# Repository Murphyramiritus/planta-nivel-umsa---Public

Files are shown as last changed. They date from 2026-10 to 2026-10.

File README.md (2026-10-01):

# Planta de Nivel - UMSA

Repositorio de la escuadra de la planta de nivel de liquido.
Asignaturas concurrentes: ETN-902, ETN-1034, ETN-1000.

## Estructura

- `documentacion/planos_isa/` - planos P&ID y electricos (.dwg y .pdf)
- `documentacion/manuales_inversa/` - fichas tecnicas del Laboratorio 1
- `database/scripts/` - modelo E-R y scripts SQL (ETN-1000)
- `middleware/` - programas de comunicacion (Modbus, dashboard)
- `historico/` - material de semestres anteriores

Los videos e instaladores no se versionan: estan en Google Drive.
Ver `historico/README.md`.

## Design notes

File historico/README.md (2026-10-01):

# Historico de semestres anteriores

Material de escuadras anteriores. Credito a sus autores.
Los videos y programas estan en Google Drive.

| Semestre | Documentacion | Videos y archivos pesados |
|---|---|---|
| 1-BITACORA | [carpeta](1-BITACORA/) | PEGAR_ENLACE_DE_DRIVE |
| 2-BITACORA | [carpeta](2-BITACORA/) | PEGAR_ENLACE_DE_DRIVE |
| 3-BITACORA | [carpeta](3-BITACORA/) | PEGAR_ENLACE_DE_DRIVE |
| del-Descripción | [carpeta](del-Descripción/) | PEGAR_ENLACE_DE_DRIVE |
| DIAGNOSTICO_SNL | [carpeta](DIAGNOSTICO_SNL/) | PEGAR_ENLACE_DE_DRIVE |
| MANUAL_INSTRUCCIONES | [carpeta](MANUAL_INSTRUCCIONES/) | PEGAR_ENLACE_DE_DRIVE |
| VIDEOS_SNL | [carpeta](VIDEOS_SNL/) | PEGAR_ENLACE_DE_DRIVE |

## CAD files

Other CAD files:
historico/2022-II/DIAGRAMAS/NIVEL.dwg
historico/2022-II/DIAGRAMAS/NIVEL_DESCRIPCION.dwg

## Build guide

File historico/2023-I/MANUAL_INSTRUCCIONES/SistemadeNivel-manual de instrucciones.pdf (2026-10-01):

# Planta nivel de liquido MANUAL DE INSTRUCCIONES

CUIDADO

1. Lea estas instrucciones
2. Conserve el manual de instrucciones
3. Tenga en cuenta las advertencias
4. Siga las instrucciones
5. No utilice este sistema en lugares que tengan una pendiente muy pronunciada
6. Límpielo regularmente para no afectar la calidad del liquido
7. no obstruya los tanques con cualquier otro material
8. coloque el cable de alimentación en modo que no ejerza presión sobre él.
9. No lo instale en una ubicación donde sea difícil trabajar con el sistema
10. Prestar atención a los protectores de corriente de cada uno de los componentes

Atención

La planta no puede trabajar mas de 12 horas debido a que puede dejar de funcionar en óptimas condiciones

Se puede producir una sobre corriente en el uso del motor, esto será visible en el protector, ya que no permitirá que se sobre limite.

Se puede percatar que las partículas de polvo estarán presenten, por ello se indica nuevamente la limpieza de los tanques.

CUIDADO

En donde se utiliza un enchufe o adaptador como dispositivo para desconectar el enchufe, este debe permanecer en buenas condiciones de funcionamiento

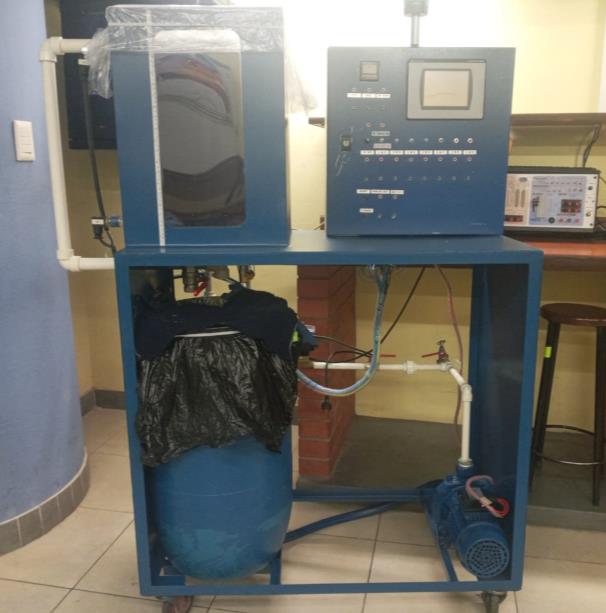
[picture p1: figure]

INDICE

### 1. COMO CONECTAR Y PREPARAR EL SISTEMA 2. FUNCIONAMIENTO BÁSICO 3. FUNCIONES DEL PLC 4. SENSOR ULTASONICO 5. ESPECIFICACIONES TÉCNICAS 6. GUÍA DE SOLUCIÓN DE PROBLEMAS DE FUNCIONAMIENTO

### 1. COMO CONECTAR Y PREPARAR EL SISTEMA 1.1 Componentes 1 Baliza de dos estados 2 Panel de control 3 Tanque de liquido 4 Tanque de líquido de retención

### 5 Bomba centrifuga 6 Sensores vibratorios 7 Sensor de presión 8 Sensor de temperatura

### 1.2 Energizar el sistema

- Conecta el cable AC al toma corriente
- seleccionar el selector eléctrico rotativo en ON

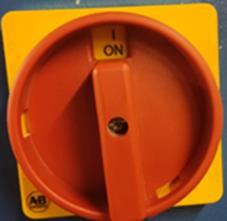
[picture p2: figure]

- Verifica el encendido de la lámpara de señalización “StandBy”

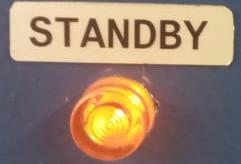
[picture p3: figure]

- Verifica el encendido de la lámpara de señalización “Ready”

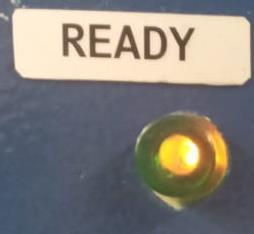
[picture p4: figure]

- Verificar el funcionamiento del dosificador y control de temperatura

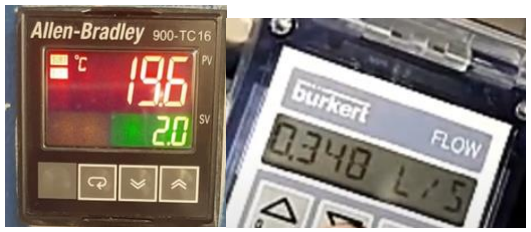
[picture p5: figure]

Visualizador de temperatura y dosificador

### 1.3 Activar todos los interruptores electromagnéticos

- Verificar el encendido del variador de frecuencia
- Verificar el encendido de las balizas.
- verificar el encendido del sensor ultrasónico y vibratorios

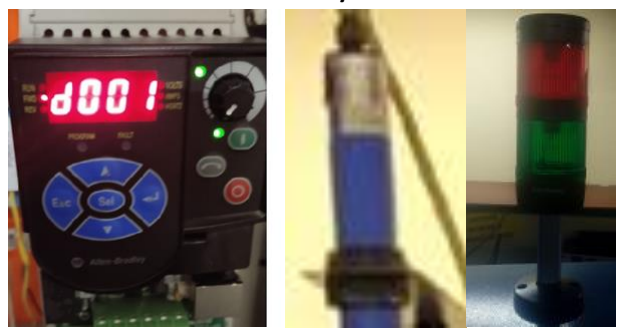
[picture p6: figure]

Variador de frecuencia, sensor ultrasónico y baliza

Activar la señal de control I0:3
- El PLC contiene el ultimo programa desarrollado en la materia

### 1.4 panel control

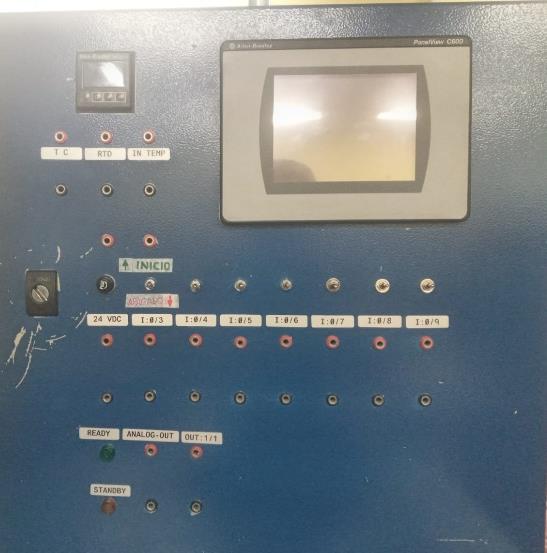
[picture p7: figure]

Para visualizar la temperatura en un sensor RTD y en sensor TC se realizarán las siguientes conexiones:

- Visualizador de temperatura
- Puertos de conexión del
visualizador de temperatura
- Interruptor de START y STOP de la planta
- puertos de conexión para los interruptores
- señalización de alimentación al sistema
- HMI

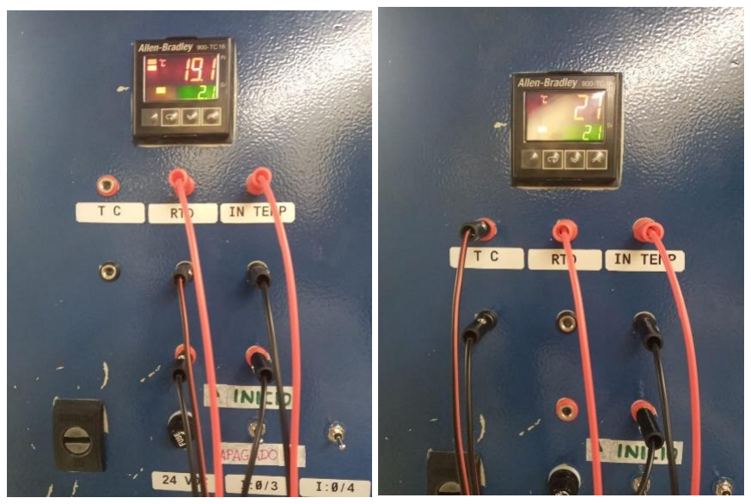
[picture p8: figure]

### 1.5 función de interruptores

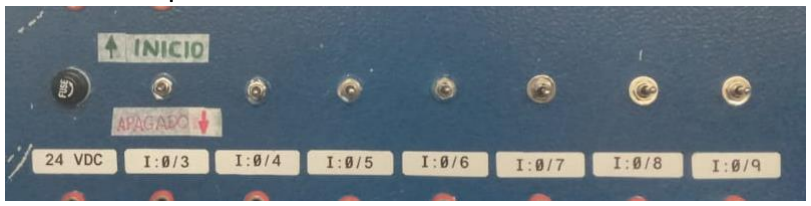
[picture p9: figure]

Se visualizan 9 interruptores de 3 estados, de los cuales, el primordial sera I:0/3 para la START Y STOP (solo usaremos 2 estados)
START (I:0/3 ==1):
- Activa la baliza a color verde
- Activa las electroválvulas NC
- Activa la alimentación de las salidas del PLC STOP (I:0/3 ==0):
- Activa la baliza a color rojo
- desactiva las electroválvulas NC
- desactiva la alimentación de las salidas del PLC

### 2. FUNCIONAMIENTO BÁSICO 2.1 Preparación de los tanques

Revisar que los tanques no presenten obstrucciones (de algún material extraño o de las válvulas manuales que se encuentran al inferior del tanque principal)

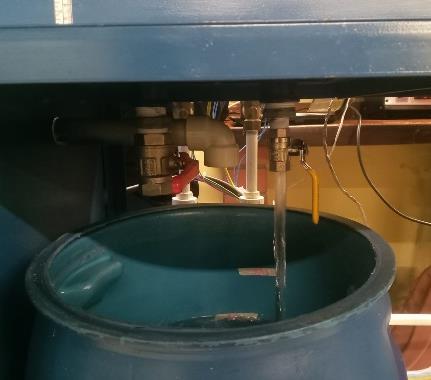
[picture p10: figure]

Válvulas manuales del tanque superior

### 2.2 encender y apagar

con el botón de encendido, realizara lo siguiente:
- el PLC obtendrá señales analógicas y mandará señal de control hacia el variador de frecuencia (conexión eléctrica).
- La altura de referencia (25 centímetros) será estable en un tiempo determinado (25 minutos).

### 2 FUNCIONES DEL PLC

El PLC tiene la función de controlar el sistema de nivel de líquido mediante la obtención de datos del nivel de líquido y la altura referencia.

### 2.1 Interfaz

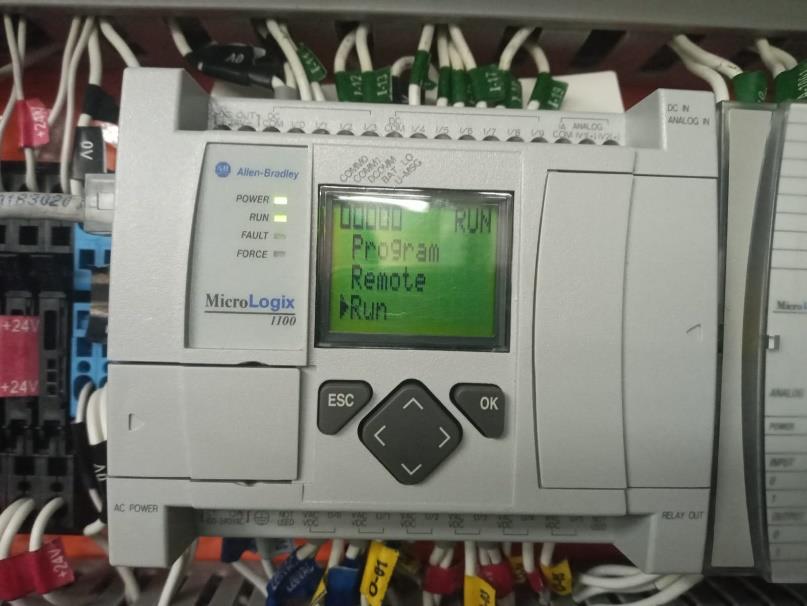
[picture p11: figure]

La interfaz principal presenta varias opciones de las cuales las que utilizaremos son: PROGRAM
RUN

### 2.2 Modo PROGRAM

Para realizar el cambio de la programación, mientras ello sucede el sistema no funciona, esto puede ser realizado con varias aplicaciones como RSx_logic.

### 2.3 Modo RUN

al aceptar el modo Run obtenemos el sistema funcionando listo para recibir las señales de encendido y apagado programadas.

### 3 SENSOR ULTRASONICO

El sensor nos ayudara a medir la altura del líquido en el tanque y recopilar la información en el PLC.

### 3.1 modo de uso

la medición de altura será proporcional a la corriente de salida de los pines del sensor (4-20mA).

### 4 ESPECIFICACIONES TÉCNICAS

Tamaño del sistema | 1.5m x 0,5m
Potencia activa del sistema | 2 kW
Capacidad del tanque inferior | 80 litros
Capacidad del tanque superior | 76 litros (aproximado)

### 5 GUÍA DE SOLUCIÓN DE PROBLEMAS DE FUNCIONAMIENTO

El sistema no enciende | - Verificar el encendido del variador de frecuencia - Verificar el encendido de las balizas. - verificar el encendido del sensor ultrasónico y vibratorios
El proceso no funciona | Verifique el variador de frecuencia este configurado correctamente. Verifique que en el PLC contenga su programa. Revise en el panel de control, la continuidad en cableado de todos los dispositivos Revise el estado de los fusibles.
No es posible poner la marcha al sistema con el interruptor I0:3 | Revisar si el PLC se encuentra en modo PROGRAMA, si es así, activar el modo RUN
El proceso funciona, pero no existe caudal de entrada | Verifique que el tanque inferior contenga líquido. Verifique el funcionamiento del actuador (Variador de frecuencia y bomba centrifuga). Verifique la correcta posición de las válvulas manuales. Verifique el funcionamiento de las electroválvulas eléctricas.
El proceso funciona de forma incorrecta | Revise el funcionamiento de los sensores (el último programa implementado en el PLC solo utiliza el sensor ultrasónico). Vuelva a calibrar el sensor de nivel(ultrasónico), para la correcta lectura de datos.

Electroválvulas no funciona correctamente Se necesita desmontar la electroválvula y verificar su funcionamiento eléctrico (energización del solenoide) . Realizar una limpieza exhaustiva a los elementos mecánicos internos, debido a la acumulación de suciedad o elementos extraños.

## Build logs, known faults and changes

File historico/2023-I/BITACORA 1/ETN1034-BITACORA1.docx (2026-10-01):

Universidad “Mayor de San Andrés”

FACULTAD DE INGENIERIA

LABORATORIO 1

CONTROLADOR DEL SISTEMA DE NIVEL DE LIQUIDO

Integrantes: Univ. Arias Llampaso Leidy Melany

Univ. Espino Marca Mary Isabel

Univ.Laura Mamani Vania Cindy

Univ. Ramos Apaza Marco Daniel

Carrera: Ing. Electrónica

Materia: Aplicación de Técnicas de Control ETN 1034

Docente: Jorge A. Nava A.

Fecha: 1/05/2023

La Paz – Bolivia

# 1. OBJETIVOS

- Reconocimiento y ubicación de los componentes del sistema (actuadores, sensores, controladores, transductores, etc.)
- Principio de funcionamientos de los componentes del sistema.
- Medir y monitorear continuamente el nivel de líquido en el tanque.
- Mantener el nivel dentro de un rango específico y controlado para garantizar un funcionamiento eficiente.
- Integrar un controlador para garantizar un monitoreo y control continuo.

# 2. DESCRIPCION DEL PROCESO

El sistema de nivel de líquido tiene como propósito medir la cantidad de líquido en un recipiente o tanque. Esto es importante en muchas aplicaciones industriales y de ingeniería, donde la cantidad precisa de líquido en un proceso es crítica para su eficiencia y seguridad.

El sistema de nivel de líquido puede ser utilizado para controlar el llenado y vaciado de un tanque, o para alertar a los operadores cuando el nivel de líquido está demasiado alto o demasiado bajo y para mantener un volumen deseado de líquido contenido en el tanque.

Del proceso también podemos obtener información sobre la presión y la temperatura.

# 3. ELEMENTOS DEL SISTEMA

## 3.1. Estructura del sistema:

- Estructura metálica color azul
- Dos tanques de almacenamiento de agua
- Soporte para sensores
- Tablero de control
- Tuberías de ½ y ¾

Tablero de control

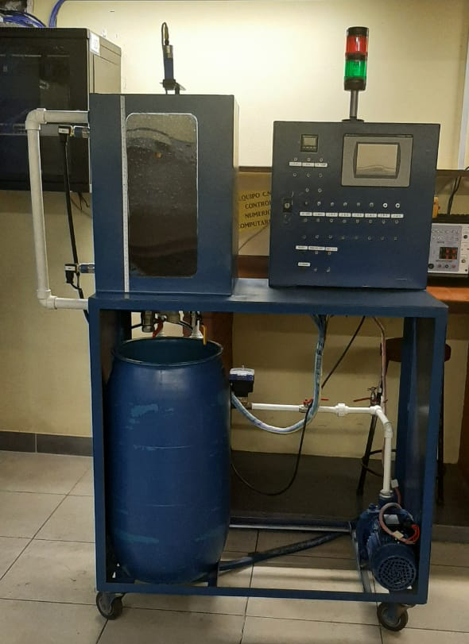
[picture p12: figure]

Tanque fijo de metal

Tanque de plástico

Tubería de ½ pulgada

## 3.2. Componentes del sistema:

- 2 sensores vibratorios
- 2 electroválvulas
- Flujómetro digital (Dosificador)
- Sensor de presión
- Sensor de temperatura TC (Termocupla)
- Sensor de temperatura RTD (Resistivo)
- Controlador de temperatura
- motor trifásico de 1HP
- Variador de frecuencia
- Sensor de Ultrasonido
- PLC (Micrologix 1100)
- 1 módulo de expansión (para PLC)
- Fuente de alimentación de 24V
- Pantalla de 6 pulgadas touch Panelview C600

Sensor ultrasónico

Sensor Vibratorio

Motor trifásico de 1 HP

Sensor ultrasónico

Controlador de temperatura

HMI

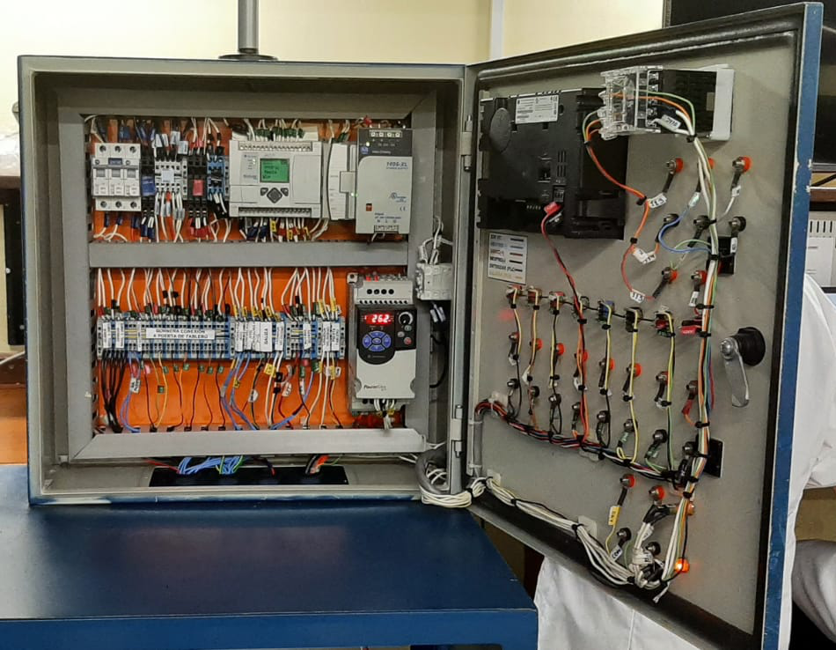
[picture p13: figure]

PLC

Módulo de expansión

Fuente de alimentación de 24 V

Variador de frecuencia

Fig. Vista frontal del sistema

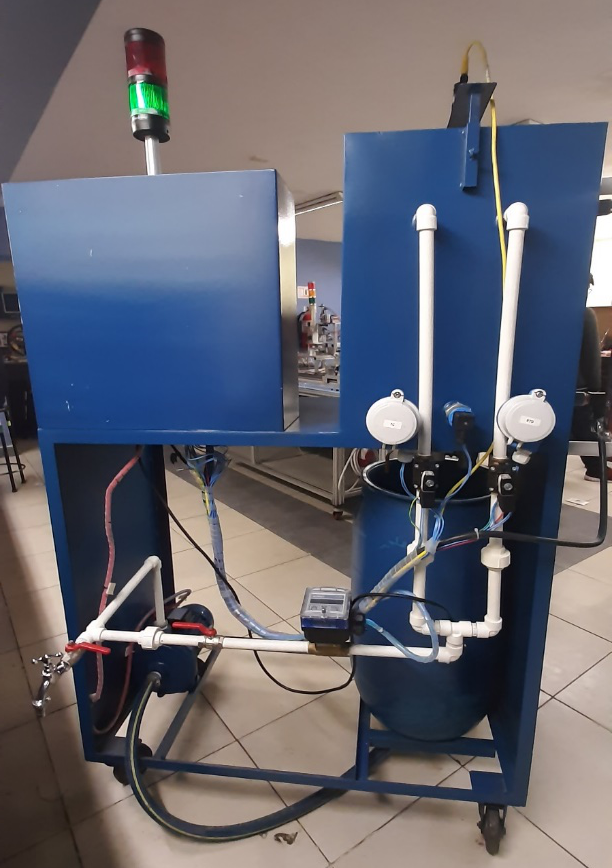
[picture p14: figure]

Sensor de Presión

Sensor de temperatura RTD

Sensor de Temperatura TC

Dosificador

Fig. Vista posterior del sistema

# 3. PROTECCION

## 3.1. Dispositivo de protección

Un termomagnético es utilizado en los sistemas eléctricos para evitar sobrecargas y cortocircuitos. Consiste en un dispositivo combinado que incluye tanto un interruptor térmico como un interruptor magnético. La función del interruptor térmico es proteger contra sobrecargas eléctricas prolongadas, es decir, corrientes excesivas que puedan dañar los cables o los dispositivos conectados. Cuando la corriente supera un cierto umbral durante un período de tiempo determinado, el interruptor térmico se activa y desconecta el circuito eléctrico, interrumpiendo el flujo de corriente.

Por otro lado, el interruptor magnético protege contra cortocircuitos, que son corrientes eléctricas muy altas que ocurren cuando hay un contacto directo entre conductores de diferentes polaridades. El interruptor magnético detecta rápidamente estas corrientes y desconecta el circuito eléctrico de manera inmediata para prevenir daños mayores.

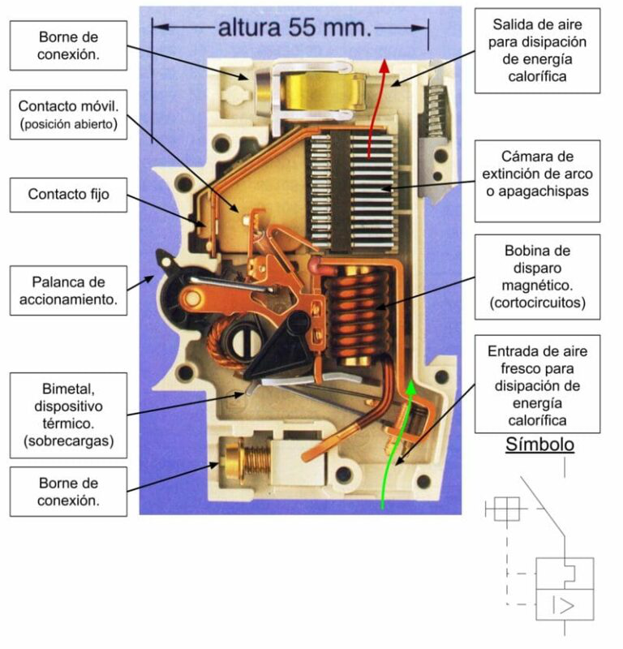
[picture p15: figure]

Los fusibles son dispositivos pequeños de seguridad que forman parte de las instalaciones eléctricas, los cuales se funden cuando la corriente alcanza ciertos valores excesivos. Se conforman por una lámina o un filamento hecho de una aleación o de un metal que se destaca por presentar un punto de fusión bajo.

Fig. Fusibles

Fig. Partes de un magnetotérmico

## 3.2. Medidas AWG

Imagen | Calibre AWG | Diámetro en MM | Consumo | Usos
| 6 | 16mm | Muy Alto | Aires acondicionados centrales, equipos industriales (se requiere instalación especial de 240 volts).
| 8 | 10mm | Alto | Aires acondicionados, estufas eléctricas y acometidas de energía eléctrica.
| 10 | 6mm | Medio-Alto | Secadoras de ropa, refrigeradores, aires acondicionados de ventana.
| 12 | 4mm | Medio | Hornos de microondas, licuadoras, contactos de casas y oficinas, extensiones de uso rudo.
| 14 | 2.5mm | Medio-Bajo | Cableado de iluminación, contactos de casas, extensiones reforzadas.
| 16 | 1.5mm | Bajo | Extensiones de bajo consumo, lámparas.
| 18 | 1mm | Muy Bajo | Productos electrónicos como termostatos, timbres o sistemas de seguridad.

En la planta se cuenta con los siguientes calibres:

CALIBRE DEL CABLEADO DEL SISTEMA DE NIVEL DE LÍQUIDO:

Fuente de alimentación | entradas y salidas | 12 AWG
HMI | Energización | AWG 18
Control de temperatura | Energización | 12 AWG
TC, RTD, presión, electroválvulas | | 16 AWG y 18 AWG
Interruptor de palanca Y CONECTORES | | AWG 18
Lámparas piloto
Sensor vibratorio | | AWG 16
Tablero | | 16 AWG
Sensor ultrasonico | | 18 AWG
PLC y módulo de expansión | | 16 AWG
Variador de Frecuencia y Bomba centrifuga | | 12 AWG

# 4. SEÑALIZACION

## 4.1. Baliza luminosa

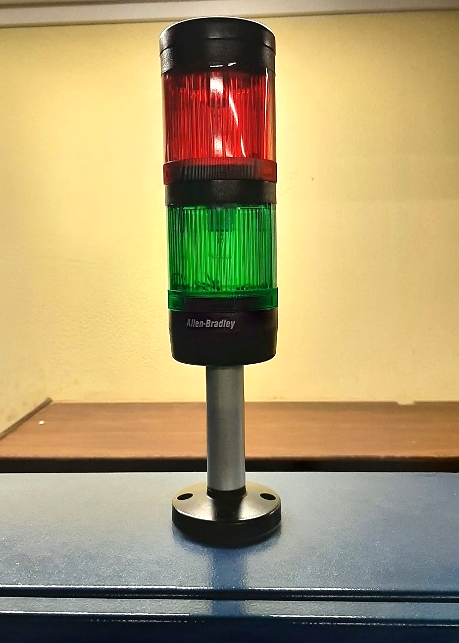
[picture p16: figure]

En un entorno industrial, una baliza es un dispositivo de señalización visual que se utiliza para indicar estados de seguridad, advertencias o información importante. Por lo general, las balizas industriales son luces de gran intensidad y colores llamativos, como rojo, amarillo o verde, a menudo se colocan en lugares estratégicos para asegurar una buena visibilidad. Las balizas industriales se utilizan para indicar el estado de un proceso, la presencia de una condición peligrosa o para llamar la atención del personal en situaciones específicas.

En nuestro sistema o kit tiene una baliza de dos colores, rojo y verde, el cual dependiendo en que etapa este, señaliza el funcionamiento del sistema, la programación depende del operador del equipo.

El sistema de señalización es simple de entender y de conectar, en este caso se usa solo los colores, los cuales están alimentados con +24 VCC

Fig. Baliza luminosa

## 4.2. Luces piloto

Las luces piloto en un sistema industrial suelen ser pequeñas luces que se utilizan para indicar el estado de funcionamiento de un equipo o sistema. Estas luces son de tamaño reducido y generalmente se encuentran en paneles de control, tableros de instrumentos o equipos individuales. Las luces piloto pueden tener diferentes colores. Las luces piloto proporcionan una indicación rápida y visual del estado de un sistema y son utilizadas por los operadores para monitorear y controlar los equipos.

Las luces piloto están disponibles para brindar control visual de que se está llevando a cabo una función eléctrica en una ubicación local o remota

Fig. Luces Piloto

# 5. ESQUEMAS

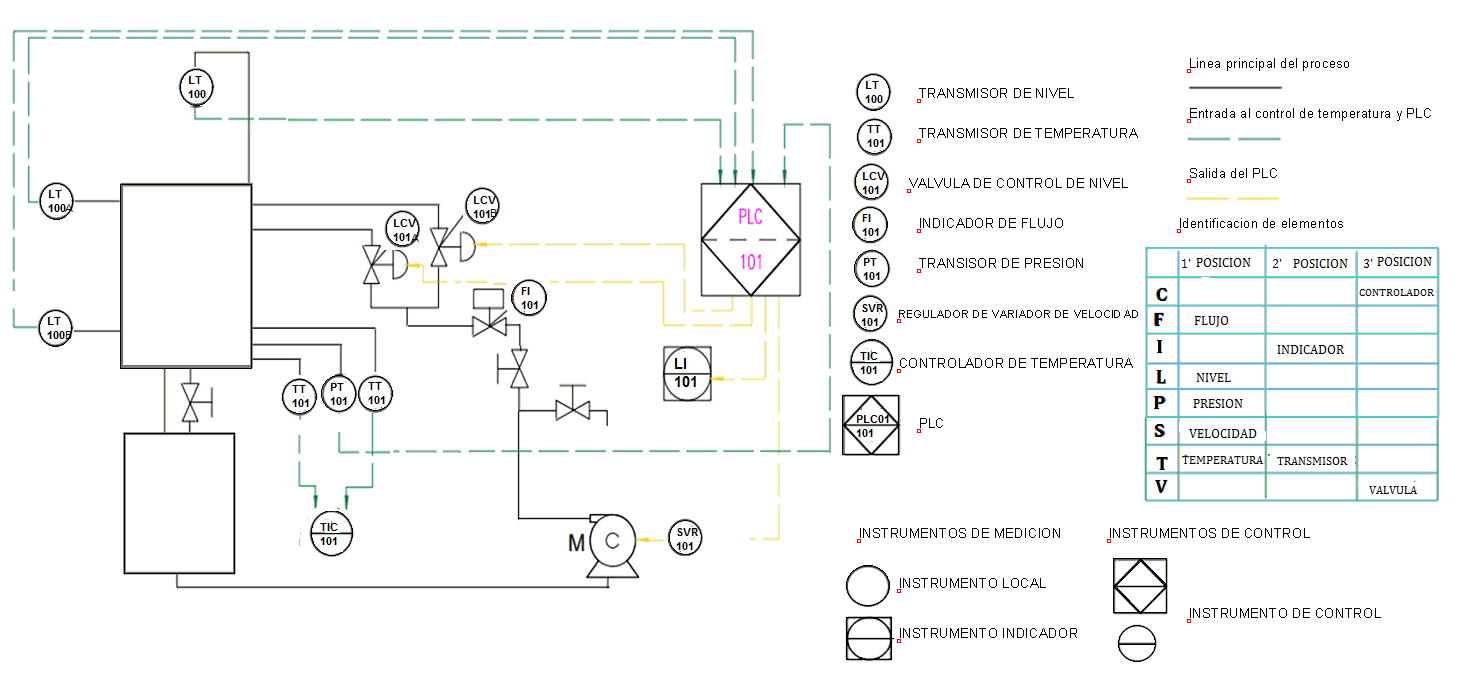
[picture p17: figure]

## 5.1. Diagrama P&ID

## 5.2. Esquema Eléctrico

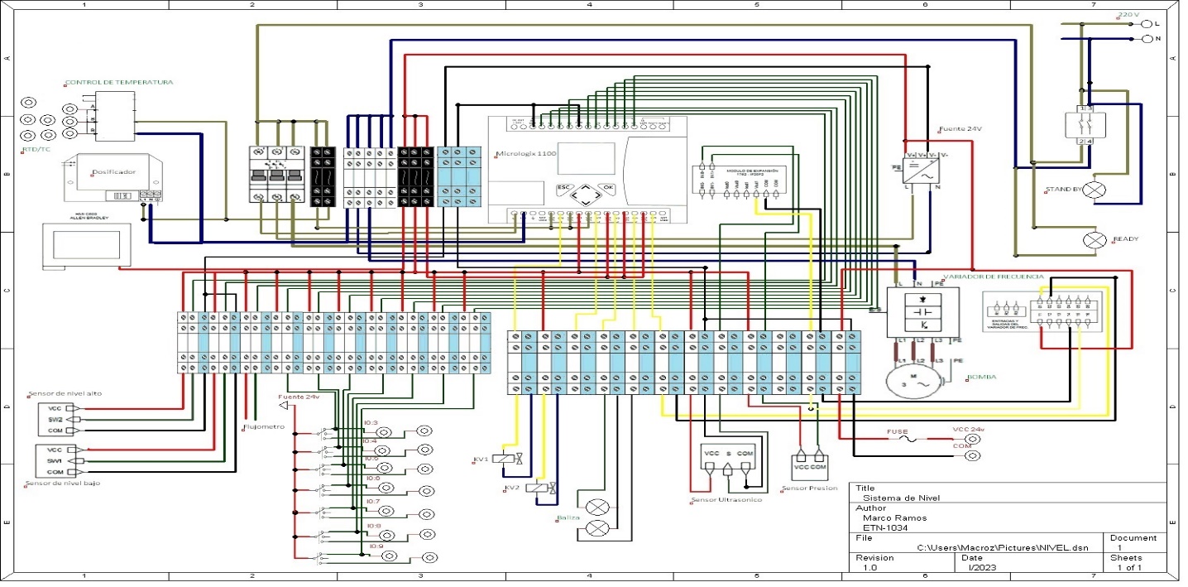
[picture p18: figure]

# 6. PUESTA EN MARCHA DEL SISTEMA

COMO CONECTAR Y PREPARAR EL SISTEMA

  - Energizar el sistema
- Conecta el cable AC al toma corriente
- seleccionar el selector eléctrico rotativo en ON
- Verifica el encendido de la lámpara de señalización “StandBy”

- Verifica el encendido de la lámpara de señalización “Ready”

- Verificar el funcionamiento del dosificador y control de temperatura

Visualizador de temperatura y dosificador

  - 1.3 Activar todos los interruptores electromagnéticos

- Verificar el encendido del variador de frecuencia

- Verificar el encendido de las balizas.

- verificar el encendido del sensor ultrasónico y vibratorios

Variador de frecuencia, sensor ultrasónico y baliza

Activar la señal de control I0:3

- El PLC contiene el último programa desarrollado en la materia
  - Panel control
- Visualizador de temperatura
- Puertos de conexión del visualizador de temperatura
- Interruptor de START y STOP de la planta
- puertos de conexión para los interruptores
- señalización de alimentación al sistema
- HMI

Para visualizar la temperatura en un sensor RTD y en sensor TC se realizarán las siguientes conexiones:

  - Función de interruptores

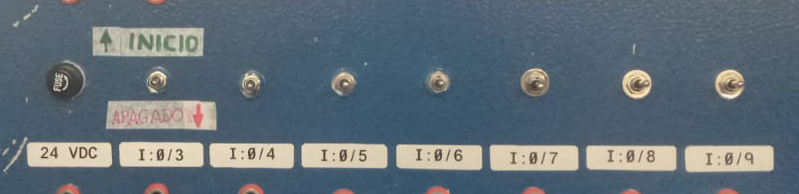
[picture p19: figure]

Se visualizan 9 interruptores de 3 estados, de los cuales, el primordial sera I:0/3 para la START Y STOP (solo usaremos 2 estados)

START (I:0/3 ==1):

- Activa la baliza a color verde
- Activa las electroválvulas NC
- Activa la alimentación de las salidas del PLC

STOP (I:0/3 ==0):

- Activa la baliza a color rojo
- desactiva las electroválvulas NC
- desactiva la alimentación de las salidas del PLC

FUNCIONAMIENTO BÁSICO

  - Preparación de los tanques

Revisar que los tanques no presenten obstrucciones (de algún material extraño o de las válvulas manuales que se encuentran al inferior del tanque principal)

Fig. Válvulas manuales del tanque superior

  - Encender y apagar

con el botón de encendido, realizara lo siguiente:

- el PLC obtendrá señales analógicas y mandará señal de control hacia el variador de frecuencia (conexión eléctrica).
- La altura de referencia (25 centímetros) será estable en un tiempo determinado (25 minutos).

FUNCIONES DEL PLC

El PLC tiene la función de controlar el sistema de nivel de líquido mediante la obtención de datos del nivel de líquido y la altura referencia.

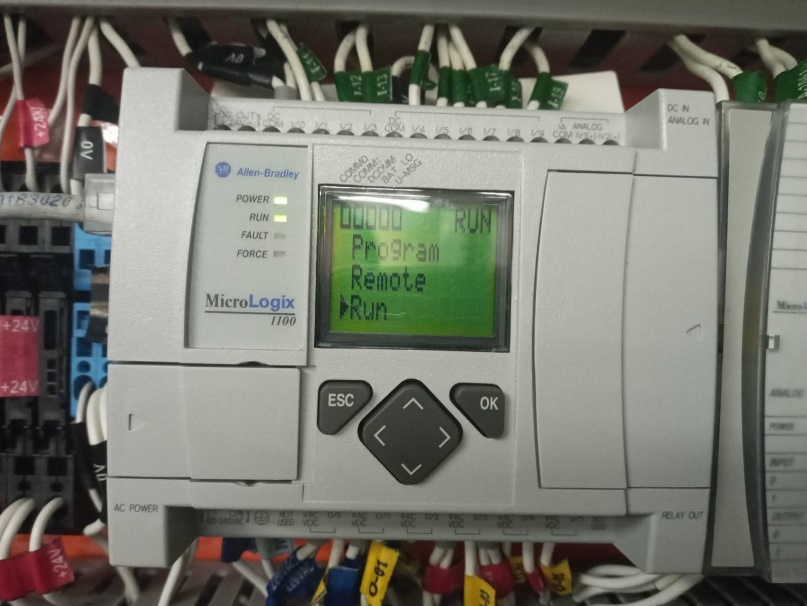
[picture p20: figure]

Interfaz

La interfaz principal presenta varias opciones de las cuales las que utilizaremos son:

PROGRAM

RUN

Modo PROGRAM

Para realizar el cambio de la programación, mientras ello sucede el sistema no funciona, esto puede ser realizado con varias aplicaciones como RSx_logic.

Modo RUN

al aceptar el modo Run obtenemos el sistema funcionando listo para recibir las señales de encendido y apagado programadas.

# 7. INSTRUMENTACION

Los instrumentos que utilizaremos en laboratorio son:

- Multímetros
- Temporizadores
- Escalas de medición
- Sensor de temperatura
- Pistola de calor
- Cable ethernet
8. COMPONENTES DEL SISTEMA

## 8.1. ACTUADORES

### 8.1.1. Variador de frecuencia

Principio de funcionamiento: La velocidad síncrona de un motor de corriente alterna (CA) está determinada por la frecuencia de AC suministrada y el número de polos en el estator, de acuerdo con la relación:

RPM=(120×f)/p

Donde:

RPM = Revoluciones por minuto

f = frecuencia de suministro AC [Hz]

p = Número de polos

24 V

0 V

O05

COM

A1012

Características POWERFLEX 4M

Entradas y salidas del variador de frecuencia:

5 entradas digitales | 2 programables
1 entrada analógica | 0 a 10 VDC
1 entrada analógica | 4 a 20 mA.
1 salida digital tipo relé

Fig Entradas y salidas del variador de frecuencia

En el sistema solo se utilizan 2 entradas digitales para realizar el arranque del motor y con la entrada analógica de 4 a 20 mA se realiza un control a 2 hilos de esta manera se puede manejar el variador de manera remota

Configuración de parámetros del motor para el variador de frecuencia:

1. Medir las conexiones
  - Entre el pin 11(24 [V]) y el pin 4(digital común) el voltaje medido es: 24,7 [V], Existen dos modos SRC y SNK
2. Restablecer a predeterminado
- P112: colocar en 1 y luego aparecerá el error f048, el cual debe ser borrado con stop.
3. Configurar voltaje placa motor
  - P101: 230[V]
4. Configurar frecuencia nominal
  - P102: 50 [Hz]
5. Configurar Corriente máxima
  - P104: 3,4 [A]
6. Configurar Frecuencia máxima y minima
- P104: 0 [Hz] min
- P105: 50 [Hz] max
7. Configurar Arranque por teclado
  - P106: “0” (modo por teclado)
8. Inhabilitar reversa
  - P104: “1” (inhabilita)

CARACTERIZACION

VARIADOR DE FRECUENCIA | VOLTAJE
0 | 0
5 | 38,8
10 | 57,5
15 | 77,3
20 | 98,1
25 | 119,3
30 | 144,4
35 | 170
40 | 195,1
45 | 219,9
50 | 229,9

### 8.1.2. Bomba centrifuga

principio de funcionamiento: Una bomba centrífuga es un tipo de bomba hidráulica que utiliza la fuerza centrífuga generada por un impulsor rotativo para aumentar la presión y mover fluidos.

- La bomba centrífuga consta de varios componentes. El impulsor es un componente clave que consta de palas curvadas que giran dentro de la carcasa de la bomba.
- Cuando el impulsor gira, crea una fuerza centrífuga que empuja el fluido hacia el exterior y hacia una zona de alta presión llamada difusor.
- El difusor es una estructura en forma de cono o voluta que rodea al impulsor y tiene la función de convertir la energía cinética del fluido en energía de presión.
- A medida que el fluido pasa a través del difusor, la velocidad disminuye y la presión aumenta

Utiliza un motor asíncrono trifásico, también conocido como motor de inducción trifásico, es un tipo de motor eléctrico que utiliza tres corrientes eléctricas alternas que son desfasadas entre sí en 120 grados para crear un campo magnético rotativo que hace girar el motor.

Este tipo de motor se compone principalmente de dos partes: el estator y el rotor. El estator es la parte fija del motor y se compone de un núcleo de hierro laminado, que contiene tres devanados de cobre, conectados en estrella o en triángulo, a través de los cuales circulan las corrientes eléctricas alternas trifásicas.

El rotor, por otro lado, es la parte móvil del motor y se compone de un conjunto de conductores de cobre dispuestos en ranuras de un núcleo de hierro laminado, los cuales están aislados eléctricamente y que forman una jaula de ardilla.

Cuando se aplica corriente eléctrica al estator, se produce un campo magnético rotativo que induce corrientes eléctricas en la jaula de ardilla del rotor. Estas corrientes crean un campo magnético en el rotor que interactúa con el campo magnético del estator, haciendo que el rotor comience a girar.

Características Pentax CMT 100/00

Q (l/min) | 20 / 90
H (m) | 32.5 / 25
HP | 1
kW | 0.74
V∆ | 230V
Vℷ | 400V
CL | Máxima temperatura de operación °F = 155°C
A | 3.4 2
Hz | 50
RPM del motor | 2800
IP 44 | Protección (resistente al agua)
Continuous Duty | Funcionamiento de motor de forma continua
3 phase | Motor trifásico para CA
CMT | Motor Centrífugo - Trifásico
00 | Armazón de hierro/Impulsor de Noryl

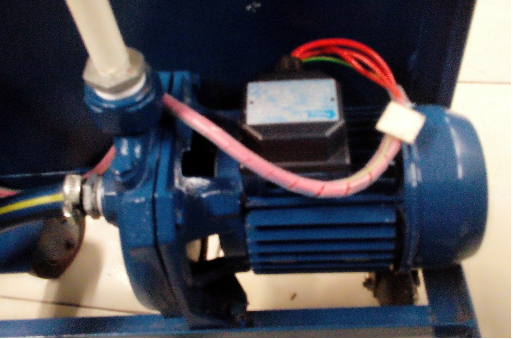
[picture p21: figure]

Fig. Bomba Centrifuga

CARACTERIZACION

FRECUENCIA [Hz] | CORRIENTE (SIN AGUA) [mA]
5 | 1,68
10 | 1,79
15 | 1,82
20 | 1,85
25 | 1,93
30 | 2,08
35 | 2,26
40 | 2,47
45 | 2,75
50 | 2,95

### 8.1.3. Electroválvulas

Principio de funcionamiento: El dispositivo cuya función es regular el flujo, en este caso hablamos del agua.

- La membrana de la válvula se apoya en el cuerpo con la ayuda del muelle y evita que el agua pase por la presión que ella misma ejerce
- Al momento de mandar una señal eléctrica al solenoide de la válvula, la bobina se imanta y levanta el embolo.
- De esta manera queda un pequeño agujero en la tapa de la válvula y permite salir al liquido de la cámara superior.
- Esto hace que funcione como un actuador que hace que se comuniquen la entrada y la salida de líquido del cuerpo de la válvula

bobina (A); armadura (B); anillo de sombra (C); muelle (D); émbolo (E); junta (F); cuerpo de la válvula (G)

CARACTERISTICAS

Fig. Electroválvula KV1

Tipo de electroválvula | 2/2 NC (2 posiciones, 2 vías, normalmente cerrado)
Suministro de voltaje 230 V AC | 230 V AC
Orificio | 13.0mm
Material de sellado | NBR
Presión nominal | 5 – 10 bar
Potencia de consumo | 4W
Temperatura de funcionamiento | 0 – 70°C

DIAGNOSTICO

- El día 13 de abril, se llevó a cabo la limpieza interna de una electroválvula que presentaba fallas en su funcionamiento.
- Se desmonto la válvula y se procedió a limpiar minuciosamente su interior, eliminando los residuos acumulados que obstruían el flujo de líquido.
- Una vez realizada la limpieza, se realizó una prueba de funcionamiento.
- Se pudo comprobar que la electroválvula funciona con normalidad y sin inconvenientes.

Fig. Electrovalvulas

## 8.2. Sensores

### 8.2.1. Sensor de vibración

principio de funcionamiento: Cuando se produce una vibración o movimiento oscilante, las horquillas oscilan en direcciones opuestas debido a su flexibilidad.

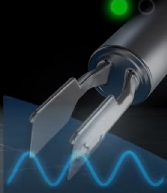
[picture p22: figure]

- Estas oscilaciones generan cambios en la resistencia eléctrica de las horquillas debido a un fenómeno conocido como efecto piezoeléctrico.
- El efecto piezoeléctrico implica que ciertos materiales generan una carga eléctrica cuando se deforman mecánicamente
- las horquillas del sensor vibratorio, están hechas de un material piezoeléctrico que genera una señal eléctrica proporcional a la amplitud y frecuencia de la vibración.
- Cuando las horquillas oscilan, la resistencia eléctrica del material cambia, lo que se traduce en una variación en la corriente eléctrica que fluye a través de ellas. Esta variación de corriente se detecta y se convierte en una señal eléctrica de salida.

Fig. Sensor vibratorio

CARACTERISTICAS

Suministro | 10-35 [V] DC
Temperatura del proceso | -40C – 150C
Presión de proceso absoluta | vacío 40 [Bar]
Densidad mínima del medio | 0.7 [g/cm^3]
Longitud del sensor | 64 [mm]
Frecuencia de medición | 1100Hz aprox. en aire
Tiempo de estabilización: | 2 [seg]

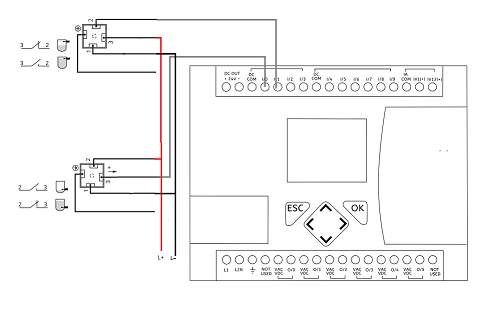
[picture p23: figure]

Fig. Sensor vibratorio inferior

### 8.2.2. Sensor de presión

principio de funcionamiento: El dispositivo detecta la presión utilizando una cavidad de presión y un diafragma de aislamiento para formar un capacitor variable

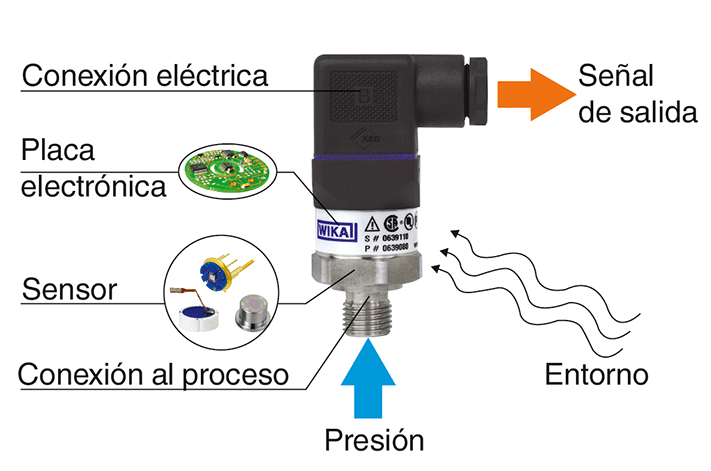
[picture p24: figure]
Cómo funciona un transmisor de presión? - Blog de WIKA

- La presión del proceso provoca una ligera desviación del diafragma de aislamiento del proceso del sensor cerámico.
- El cambio proporcional a la presión en la capacitancia se mide en los electrodos del sensor cerámico
- Este cambio en la capacidad se puede medir eléctricamente y correlacionarse con la presión aplicada
- El sensor capacitivo no requiere liquido de llenado, por tanto, también puede trabajar en aire.

CARACTERISTICAS CERABAR T-PMC131

Tipo de sensor de presión | Sensor capacitivo de cerámica
Suministro de voltaje | 11 – 30 [V] DC
Temperatura del proceso | -20C – 100C
Celda de medición | 100 mbar – 40 Bar
Limite máx.. de sobre presión | 60 bar
Comunicación | 4- 20mA (analógico)
Potencia máxima | 6W

Fig. Sensor de presión

DIAGNÓSTICO

No se encontró ninguna observación visual, externa e interna, debido a ello se procedió a realizar pruebas de funcionamiento y obtener una tabla de valores respecto con el llenado del líquido.

CARACTERIZACION

Altura [cm] | Corriente prueba [mA]
0 | 3,8
5 | 4,2
10 | 4,2
15 | 4,7
20 | 5,19
25 | 5,4
30 | 5,8
35 | 6,3
40 | 6,72

### 8.2.3. Sensor de temperatura TC

PRINCIPIO DE FUNCIONAMIENTO

Los termopares son sensores de temperatura robustos cuyo principio de medición se basa en el efecto Seebeck.

- Consta de dos hilos metálicos homogéneos pero diferentes entre sí y aislados en toda su longitud. Los dos cables son soldados juntos en un extremo
- El extremo es llamado “unión caliente o de medición” y el otro extremo es conocido como “unión fría o de referencia”
- Cuando se conectan en un punto los dos conductores eléctricos de distintos materiales, puede medirse una tensión eléctrica débil entre los dos extremos abiertos
- Siempre que haya un gradiente de temperatura en los conductores, esta tensión es denominada “tensión termo eléctrica”

CARACTERISTICAS TERMOCUPLA TD12

Tipo de sensor | TC12 “J” termómetro TC modular
Rango de temperatura de operacion: | -40°C – 750°C
Máxima presión de proceso | a 20°C es 40 bar (580psi)
Consumo de corriente | < 50mA
Rango de temperatura | - 20 °C– 70 ° C
Material | plástico - PBT

Fig. Sensor de temperatura TC

DIAGNOSTICO

El sensor no presentaba daños visualmente, por lo que se procede a realizar las pruebas de funcionamiento.

Por lo que procedemos a conectar el los pines del sensor un termómetro digital para obtener los datos de salida.

Multímetro °C | T[°C] | V[mV]
24 | 26 | 0
30 | 30 | 0,1
40 | 46 | 0,1
50 | 64 | 0,3
60 | 78 | 0,6
70 | 97 | 0,8
80 | 109 | 1
90 | 124 | 1,3
100 | 137 | 1,4
110 | 150 | 1,7
120 | 172 | 2,2
130 | 182 | 2,3

### 8.2.4. Sensor de temperatura RTD

principio de funcionamiento: El dispositivo realiza medidas de temperatura utilizando como factor principal de medición la resistencia de un metal.

- La resistencia del alambre de metal se transforma con relación a la temperatura, el funcionamiento de la RTD comienza al calentarse un metal
- Esta acción permite un aumento de temperatura induciendo una mayor agitación térmica y aumento de la resistencia.
- Se maneja el concepto de a mayor temperatura, mayor agitación y mayor Resistencia y a menor temperatura, se tiene menor agitación y menor Resistencia.
- La relación resistencia-temperatura se representa con la siguiente formula: R=Ro[1+a(T-To)]

CARACTERISTICAS RTD OMNIGRAND T TST487

Tipo | A, Métrico, porta sondas de temperatura modular conexión a proceso roscada sin cuello
Elemento sensible | Resistencia de platino
Conexión a proceso | Rosca macho G1/2
Rango de temperatura | -50°C – 300°C
Max. Presión de proceso | a 20°C 20bar
Alambrado | Conexión de 4 hilos, aislamiento de fibra de vidrio.

CARACTERIZACION

Fig. Sensor de temperatura RTD

MULT. °C | T[°C] | V [mV] | I[mA] | R[Ω]
40 | 44 | 118 | 1 | 118
60 | 71,4 | 127,8 | 1 | 127,8
70 | 87,5 | 134,6 | 1 | 134,6
80 | 92,9 | 136,4 | 1 | 136,4
90 | 98,7 | 138,6 | 1 | 138,6
100 | 104,1 | 141 | 1 | 141
110 | 110,8 | 142,8 | 1 | 142,8
120 | 131,8 | 150,9 | 1 | 150,9
140 | 134,5 | 151,6 | 1 | 151,6
150 | 150,1 | 157,7 | 1 | 157,7
160 | 154,9 | 158,9 | 1 | 158,9
170 | 159,3 | 160,2 | 1 | 160,2
180 | 167,7 | 163,7 | 1 | 163,7
190 | 170,5 | 164 | 1 | 164
200 | 179,1 | 168,7 | 1 | 168,7

### 8.2.5. Sensor ultrasónico

PRINCIPIO DE FUNCIONAMIENTO

Se basa en el principio de medida “Time of flight” y van detectando continuamente el nivel del líquido en el tanque

- Pulsos ultrasónicos son emitidos reflejados en la superficie del líquido y son recibidos por el sensor
- La distancia entre el instrumento y el líquido se puede calcular midiendo el “tiempo de vuelo”.
- Las ondas ultrasónicas, son ondas mecánicas, generados piezo- eléctricamente y reflejados en la superficie del líquido debido a la diferencia de densidad entre el aire y el liquido
- El periodo de tiempo medido y analizado por el instrumento, entre enviar y recibir el pulso, es una medida directa para calcular la distancia entre la membrana del sensor y la superficie del liquido

CARACTERISTICAS

Suministro de voltaje | 12 – 30 V DC
Salida | corriente analógica 4-20mA
Salida | Voltaje analógico 0-10 V
Rango de medición | 150 – 1500mm
Consumo de corriente | < 45mA
Rango de temperatura | - 20 – 70°C
Protección contra corto circuitos y sobrecarga

DIAGNOSTICO

El sensor ultrasónico no presentaba ningún problema visualmente, por lo que se procedió a probar su funcionamiento.

- El sensor inicialmente ya presentaba una calibración, pero se procedió a realizarlo nuevamente.
- Se realizaron las medidas máximas de distancia, que será la menor altura (H=0) y la mínima distancia (Hmax)
- La calibración se la realiza mediante el botón de configuración y se procede a guardar el rango de distancia de trabajo con ayuda de la hoja técnica.
- Una vez calibrado, procedemos a realizar la prueba de funcionamiento obteniendo la table de datos a continuación.

CARACTERIZACION

Altura del tanque [cm] | Corriente [mA]
20 | 19,1
25 | 17,1
30 | 15,1
35 | 13
40 | 10,9
45 | 8,8
50 | 6,8
55 | 4,8

SENSOR ULTRASONICO CON P1=56,8cm y P2=15cm

Altura del tanque [cm] | Corriente [mA]
0 | 3,7
5 | 5,3
10 | 7,1
15 | 9
20 | 11
25 | 12,8
30 | 14,7
35 | 16,5
40 | 18,4
45 | 19,3

## 8.3. AUTÓMATAS

### 8.3.1. Controlador lógico programable PLC

Funcionamiento: Detecta diversos tipos de señales del proceso, elaborar y enviar acciones, recibe configuraciones de los operadores y da reporte a los mismos.

Partes principales son la CPU, un módulo de memorias y de entra das/salidas, la fuente de alimentación y la unidad de programación.

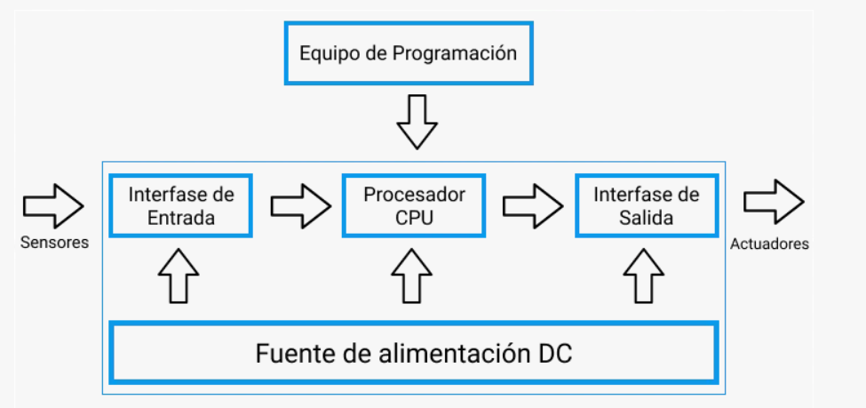
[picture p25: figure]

Fuente de alimentación DC
Módulos de entrada y salida
Unidad de procesamiento central (CPU)
Equipo de programaciónEstructura de un PLC

Módulos de entrada y salida (E / S)

- Son de dos tipos. Puede ser digital o analógico.
- Se debe proporcionar información al controlador PLC.
- M.E: Proporcionan una interfaz para dispositivos de entrada como diferentes tipos de interruptores (interruptor de botón, interruptor selector, interruptor limitado), sensores, etc.
- M.S: proporcionar una interfaz para dispositivos de salida como motor, ventilador, relé, luz, lámpara, calentador eléctrico, válvula solenoide, zumbador, etc.

Fuente de alimentación

- Proporciona energía a todos los demás componentes para operar. Proporciona energía a los módulos de entrada / salida, sistema de memoria y procesador.
- Proporcionar la alimentación de CC o CA para operar el PLC.

Unidad de procesamiento central (CPU)

- La función de la CPU es almacenar y ejecutar los programas de software.
- Es la parte que se encarga del procesamiento de la información y está basado en un microprocesador y memorias.
- La unidad de memoria se comunica con el microprocesador para leer y escribir información.

Sistema de memoria

Todo PLC posee una memoria organizada en área de trabajo específicas que son:

- ROM (Read only memory). Memoria de solo lectura o memoria del sistema operativo y no es accesible por el usuario, allí se almacenan los programas.
- RAM (Random access memory). Memoria de acceso aleatorio, memoria de datos o memoria de usuario, es una memoria volátil, almacena la información de las variables de entrada y salida.
- Memoria insertable (EPROM, EEPROM). Si se quiere garantizar totalmente el contenido de la información sin que se pierda el programa efectuado, éste deberá almacenarse y grabarse en memorias EPROM o EEPROM que son de tipo chips.

CARACTERISTICAS MicroLogix 1100

Memoria | Memoria programable de 64 Kb y memoria de datos de 1 Mb
Entradas digitales | 10
Salidas a Rele (NA/NC) | 6
Fuente de alimentación | 24 VDC
Comunicación | Multiples opciones de comunicación, incluyendo Ethernet, RS-232
Velocidad de procesamiento | 1.5 us por instruccion

Fig. Controlador Lógico Programable

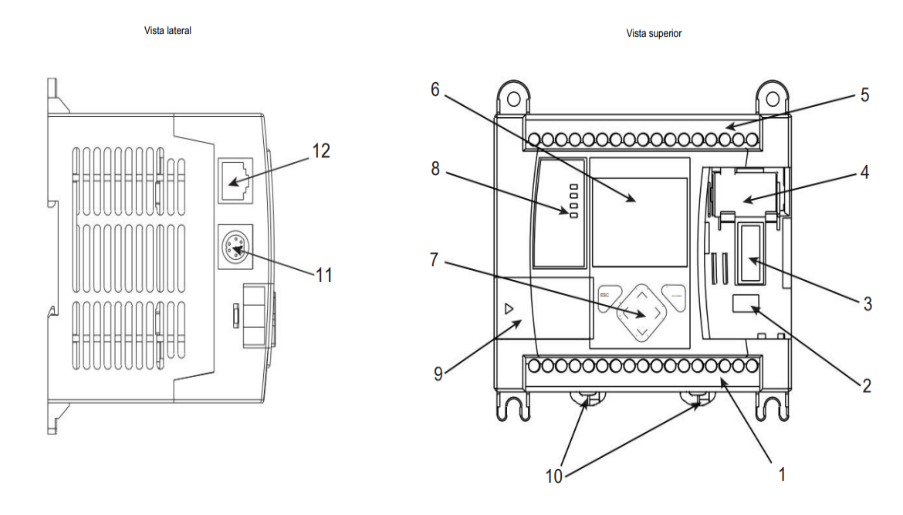
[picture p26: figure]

CARACTERISTICAS DEL HADWARE

CARACTERISTICA | DESCRIPCION
1 | Bloque de terminales de salida
2 | Conector de batería
3 | Interfaz de conector de bus a e/s de expansión
4 | Batería
5 | Bloque de terminales de entrada
6 | LDC
7 | Teclado lcd (esc, ok, arriba, abajo izquierda, derecha)
8 | Indicadores led de estado
9 | Cubierta del puerto del módulo de memoria 1 o 2
10 | Pestilos de riel
11 | Puerto de comunicaciones rs-232/485 (canal 0, aislado)
12 | Puerto ethernet

### 8.3.2. Módulo de expansión del PLC

PRINCIPIO DE FUNCIONAMIENTO

Los Controladores Lógicos Programables pueden ampliar su funcionalidad con un hardware que es agregado para permitirle ampliar aspectos como las: entradas digitales, entradas analógicas, salidas digitales, salidas analógicas, salidas tipo relé y por supuesto distintos protocolos de comunicación.

¿Para qué sirven los módulos de expansión?

Los módulos de expansión plc permiten ampliar el número de entradas y salidas que este posee, cuando su capacidad no cumple con los requerimientos de una aplicación de automatización.

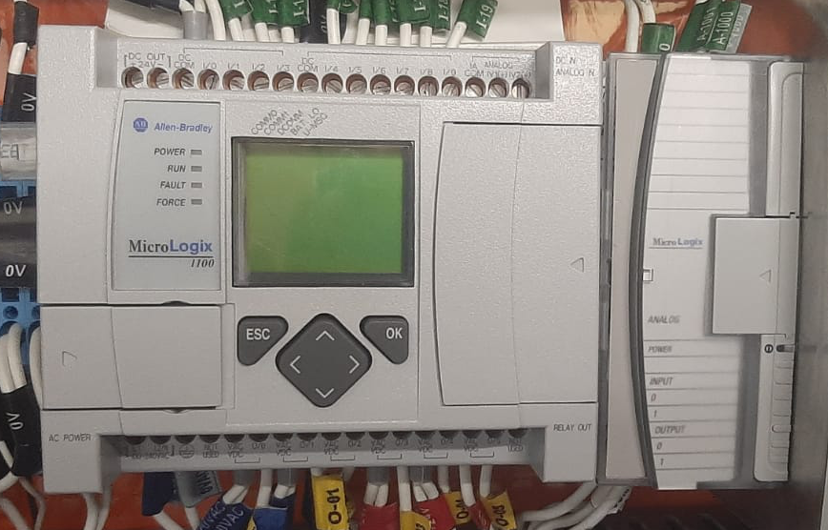
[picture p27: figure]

CARACTERISTICAS Módulo de expansión 1762-IF20F2 de Hallen Bradley

Tipo de entrada | Analogico
Temperatura máxima de funcionamiento | +65 °C
Temperatura de trabajo mínima | -20 °C
Número de entradas | 2
Número de salidas | 2 (single-ended)
Corriente de salida | 20 mA
Tipo de salida | Analógico

Fig. Modulo de expansión PLC

## 8.4. Elementos de visualización

### 8.4.1. HMI

Es una pantalla gráfica que muestra información sobre el estado del sistema, permite al operador ingresar comandos y configuraciones, y alerta al operador de cualquier problema o falla en el sistema.

### 8.4.2. Controlador de temperatura

Funcionamiento: El controlador utiliza un sensor de temperatura para medir la temperatura actual del sistema. Los sensores comunes incluyen termopares, termistores o RTD (Detector de temperatura de resistencia).

Visualización de temperatura RTD y TC

Como se puede ver, el controlador no forma parte del sistema, somo se utiliza para la visualización de temperatura del liquido

### 8.4.3. Dosificador

principio de funcionamiento: Cuando el líquido fluye a través de la tubería, la rueda de paletas con 4 imanes insertados se pone en rotación, produciendo una señal de medición en el sensor.

El voltaje inducido modulado en frecuencia es proporcional a la velocidad de flujo del fluido.

Los valores nominales de presión y temperatura deben respetarse de acuerdo con el material de montaje del sensor seleccionado.

El tamaño de tubería adecuado se selecciona utilizando el diagrama para seleccionar el diámetro nominal del accesorio del sensor.

Un factor K, específico para cada tubería (tamaño y material) permite convertir esta frecuencia en un caudal

FUNCION:

Controlar y medir el volumen de líquido proporcionado al sistema.

- Proporciona información del caudal de líquido que pasa a través de las tuberías. Todo esto gracias a un rodete que gira en proporción al fluido que pasa por la tubería.
- Tensión de alimentación: 115/230 VCA y cuenta con 2 relés para realizar la dosificación.

DESCRIPCION DE TIPO

- El caudalímetro o dosificador 8035 es apto para la medición/dosificación de líquidos neutros o ligeramente agresivos sin sólidos en suspensión.
- El caudalímetro se compone de un racor de conexión con sensor integrado y un transmisor electrónico que se conectan entre sí, de una forma rápida y sencilla, mediante un sistema de bayoneta.
- Indicación del caudal instantáneo y dos totalizadores.
- Simulación de las salidas sin presencia de fluido.
- Para modelo dosificador: Contador de cantidades totales y diarias e indicador de dosificación por volumen o peso.

El dosificador 8035 cuenta con 3 tipos de dosificación

- Dosificación en modo manual
- Dosificación en modo automático

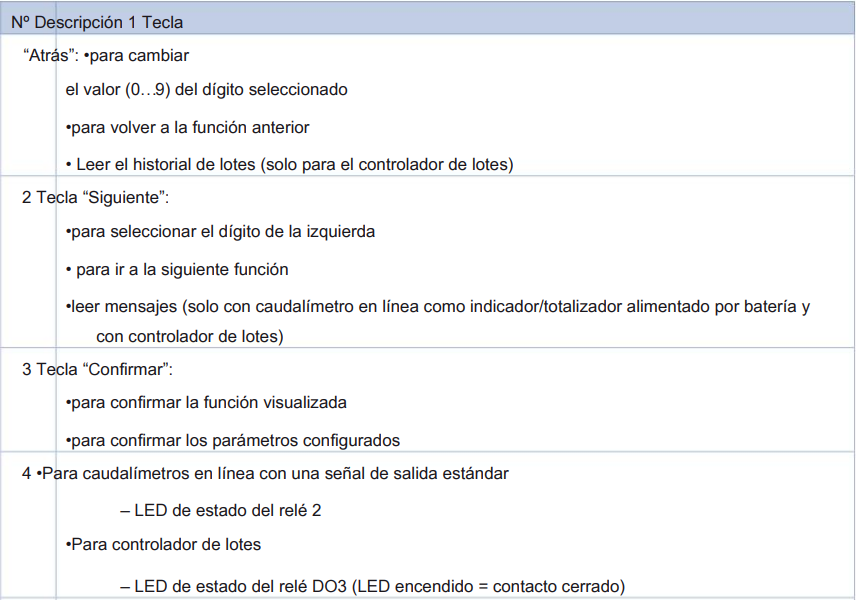
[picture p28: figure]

- Dosificación manual y automática

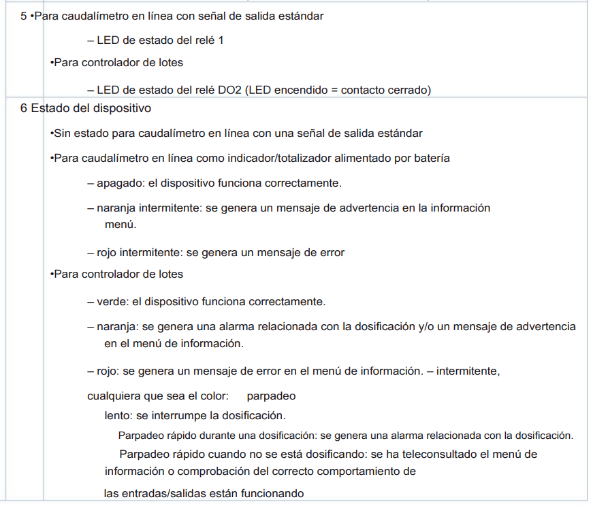
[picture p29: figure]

# 9. ARREGLOS

## ELECTROVALVULA

- El día 13 de abril, se llevó a cabo la limpieza interna de una electroválvula que presentaba fallas en su funcionamiento.
- Se desmonto la válvula y se procedió a limpiar minuciosamente su interior, eliminando los residuos acumulados que obstruían el flujo de líquido.
- Una vez realizada la limpieza, se realizó una prueba de funcionamiento.
- Se pudo comprobar que la electroválvula funciona con normalidad y sin inconvenientes.

Fig. Electrovalvulas

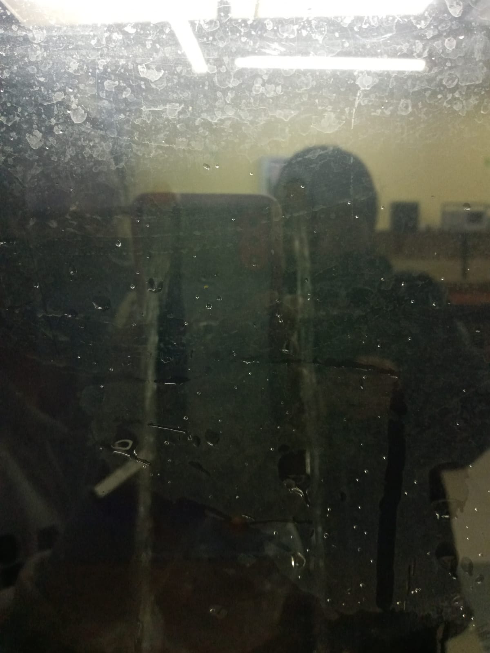
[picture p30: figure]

Desmontaje

Montaje

Funcionamiento

CONTROLADOR DE TEMPERATURA

- El día 18 de abril, se llevó a cabo el refuerzo de las conexiones de cables en el controlador de temperatura NOMBRE para evitar la pérdida de voltaje al cerrar la compuerta que lo sostiene.
- Se detecto que las conexiones presentaban una sujeción deficiente, lo que provocaba una fluctuación en voltaje y una inestabilidad en el funcionamiento del equipo.
- Se procedió a reforzar las conexiones mediante el uso de tornillos, asegurando una sujeción más firme y estable.

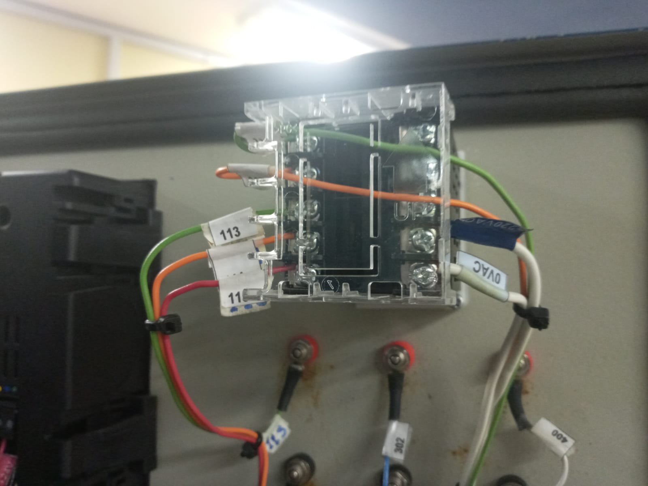
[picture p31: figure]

- Se realizo una prueba de funcionamiento y se confirmó que el controlador de temperatura está funcionando correctamente.

Panel frontal

Parte posterior (conexiones del controlador de la temperatura)

Las conexiones que presentaban una sujeción deficiente corregidas.

### 9.1. LIMPIEZA DEL SISTEMA

- El día 20 de abril, se llevó a cabo la limpieza del sistema del sistema de nivel de líquido. Se verifico que el nivel de agua se encontró en óptimas condiciones.
- Se procedió a retirar la suciedad acumulada (polvo y agua residual) para asegurar un buen funcionamiento.
- Se utilizo:
- Guantes, detergente, agua limpia, trapos y Escoba.
- Finalmente se realizó una prueba de funcionamiento y se confirmó que el sistema de nivel de líquido está operando correctamente.

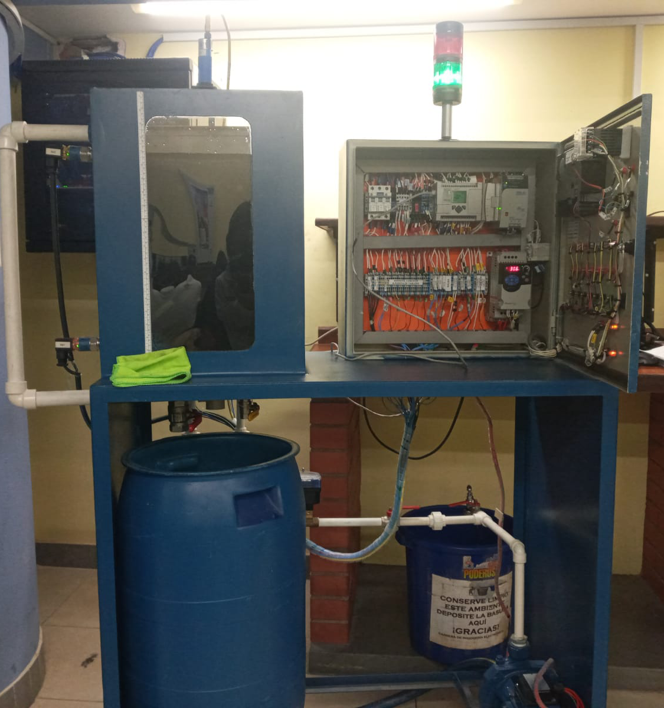
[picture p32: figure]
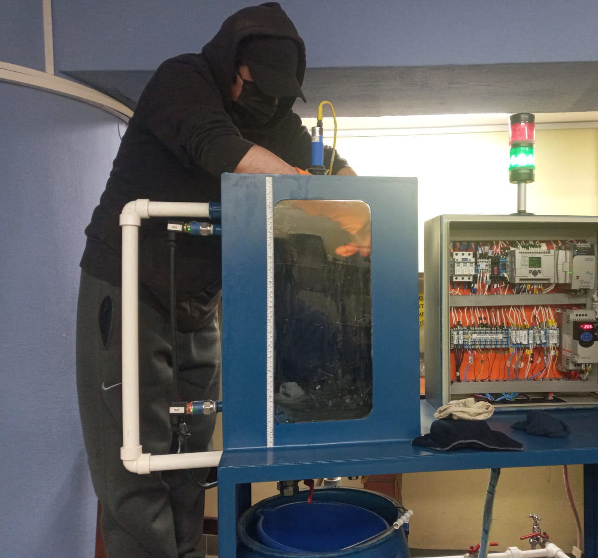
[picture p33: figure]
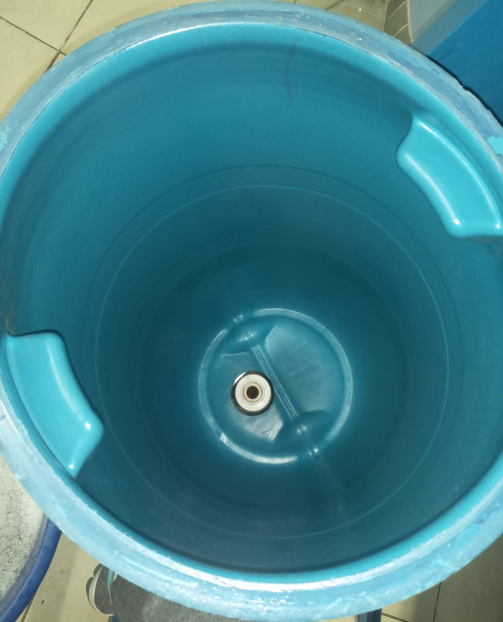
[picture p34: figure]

Limpieza

Antes delimpieza

después

Despues de la limpieza

# 10. MODIFICACIONES AL SISTEMA

TUBOS PVC

- El día 24 de abril, se realizó el aumento en los tubos PVC del sistema de nivel de agua para corregir el caudal de líquido que caía desde la pared del tanque en lugar de caer desde arriba.
- Se verifico que la instalación original no permitía mantener una altura de líquido adecuada y esto afectaba el funcionamiento del sistema
- Se procedió a desmontar los tubos PVC existentes y a instalar nuevos tubos con una mayor inclinación, permitiendo que el caudal de agua caiga desde arriba de manera adecuada.
- Una vez finalizada la instalación, se realizó una prueba de funcionamiento y se confirmó que el sistema de nivel de líquido está operando correctamente.

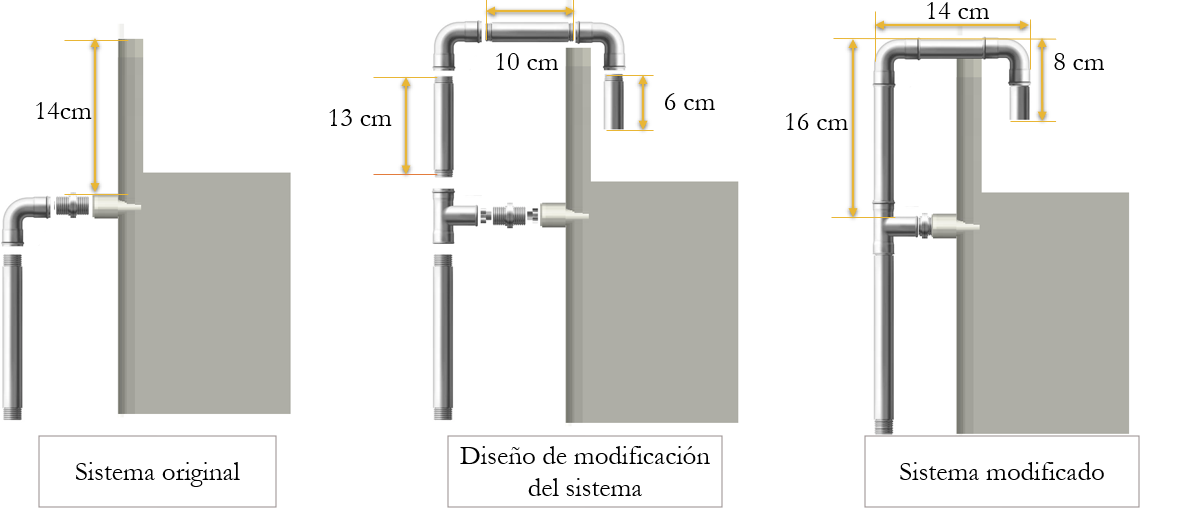
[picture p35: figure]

Herramientas utilizadas

- 2 tubos tipo T de ½ pulgada
- 2 codos de ½ pulgada
- 1 tubo PVC de 1 metro
- Teflón
- Llave de presión
- Llave de pivote
- Llave de triquete
- Tarraja manual
- Poxipol
- Sierra mecánica
- 2 tapones PVC macho de ½ pulgada

# 11. CONCLUSIONES

- Se verifico que uno de los soportes de la pantalla HMI estaba fracturada, pero el equipo no fue desmontado por el momento.
- Se verifico que el equipo presentaba fugas de líquido en las conexiones de tubo PVC lo que provocaba un peligro en las conexiones eléctricas, se realizó un mantenimiento preventivo reajustando las conexiones.
- Además, se observó que el soporte del caudal de entrada presentaba debilidad, lo que generaba inestabilidad en la posición de los tubos al realizar el diseño para el aumento de tubos PVC. Se reforzo el soporte con la conexión de T para asegurar a los tubos.
- Finalmente se constató que el tanque requiere una tapa, debido a que exponía al liquido a la contaminación externa y afectaba la calidad del líquido, por tanto, se puso una bolsa de forma provisional para no exponer al líquido.

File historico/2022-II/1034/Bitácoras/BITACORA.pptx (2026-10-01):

## SISTEMA DE NIVEL DE LÍQUIDO

UNIVERSIDAD MAYOR DE SAN ANDRES
FACULTAD DE INGENIERIA
INGENIERIA ELECTRONICA

Integrantes: Alvaro Jonny Ortega Quispe
Milton Rodrigo Tiñini Vallejos
Docente: Ing. Jorge Antonio Nava Amador
Materia: ETN 1034

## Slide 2

- Milton: 3, 8-10, 17, 31-40,44-58, 66
- Alvaro: 4-7, 11-16, 18-30, 41-43, 59-65

## OBJETIVOS

- Caracterizar al proceso en su totalidad utilizando la normativa ISA (P&ID)
- Utilizar la instrumentación de laboratorio
- Caracterizar los elementos que componen al sistema
- Realizar la adaptación de señales para aquellos transductores en los que sea necesario.

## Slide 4

SISTEMA DE NIVEL

## Estructura del sistema (tablero de control)

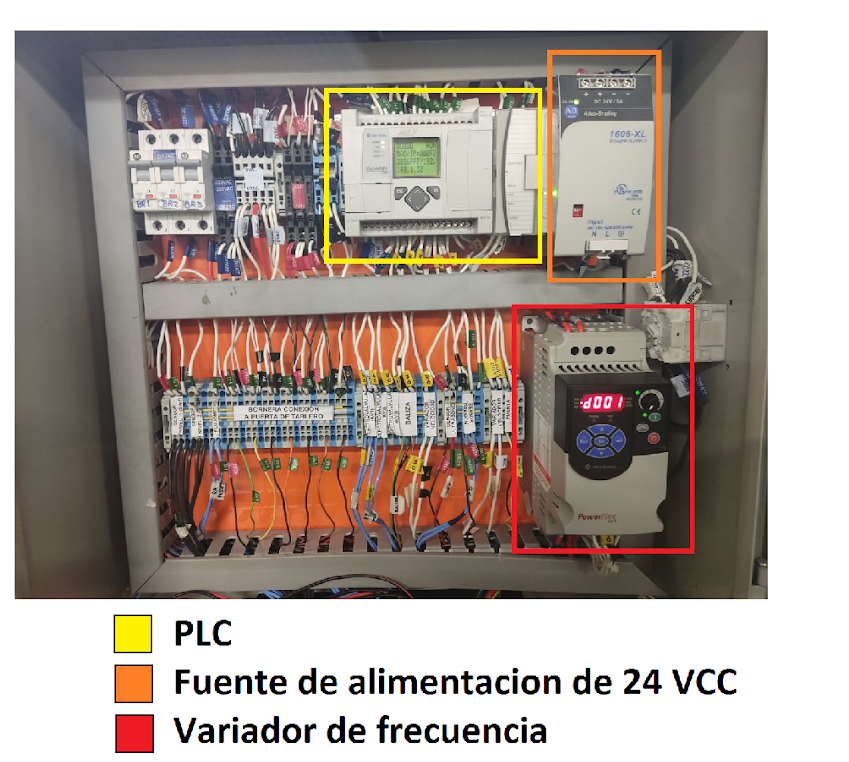
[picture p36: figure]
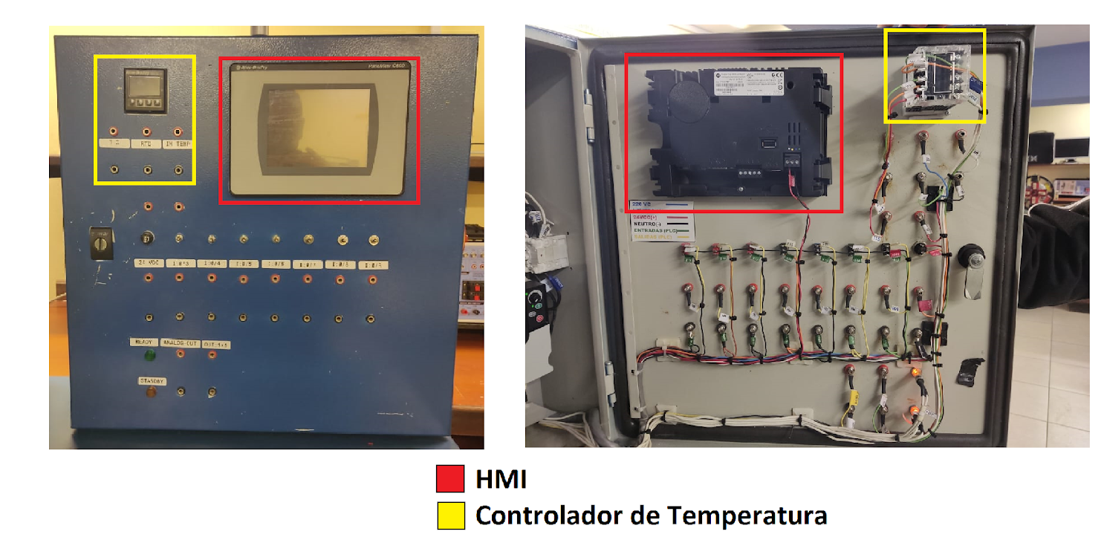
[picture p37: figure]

Interior del panel de control

Parte frontal e interna de la puerta del tablero de control

## Estructura del sistema (vista frontal)

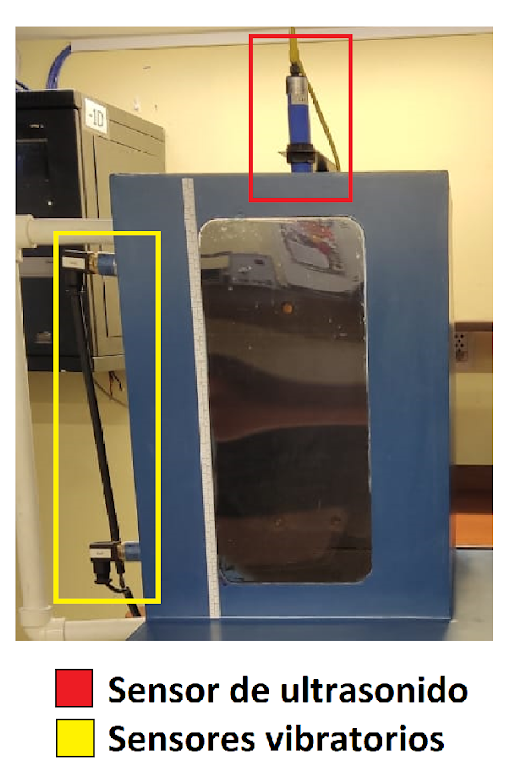
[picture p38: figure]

Tanque inferior (Reserva de agua)

## Estructura del sistema (vista trasera)

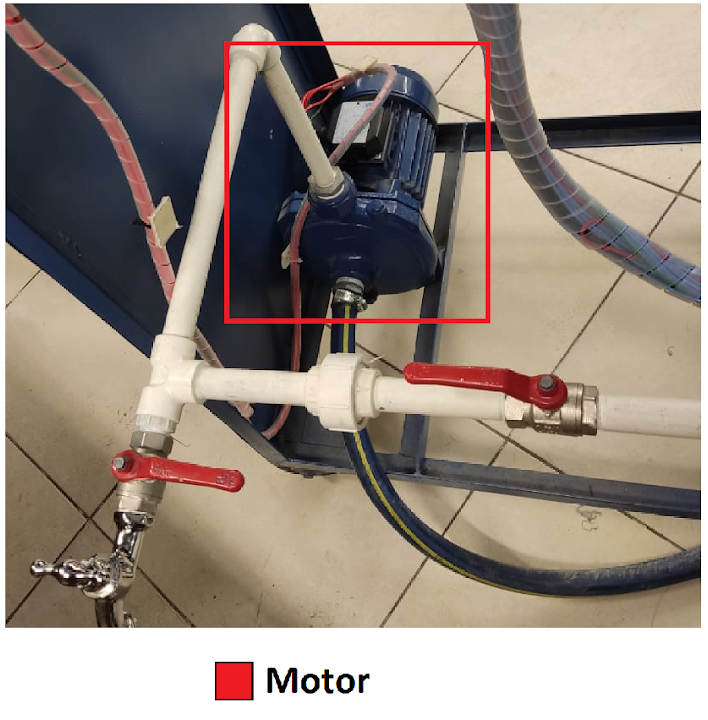
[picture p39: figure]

## FUNCIONAMIENTO DEL SISTEMA

- Sensores vibratorios: Es utilizado para la detección de nivel alto y bajo del líquido en el tanque.
- Sensor ultrasónico: Es utilizado para la medición de la altura del nivel de líquido del depósito.
- Sensor de presión: Es utilizado para la medición de presión relativa en el tanque y también se puede usar para medir la altura del líquido teniendo como referencia la posición de este sensor.
- Sensores de temperatura TC/RTD: Están conectados al controlador de temperatura para dar mediciones de la temperatura del líquido.
- Controlador de temperatura: Este controlador es utilizado como un indicador de temperatura, sin aprovechar su capacidad de realizar una acción de control.
- Flujómetro (Dosificador): Utilizado para la medición del caudal y volumen del líquido.
- Electroválvulas: Permiten el cierre o paso del líquido por la red de cañerías.
- Variador de frecuencia: Permite regular la velocidad de giro del motor, mediante la variación de frecuencia del mismo, de manera que se pueda bombear el líquido del tanque inferior al superior.
- Motor. (bomba) Actuador encargado de llevar el líquido del tanque inferior al tanque superior para el llenado y control del mismo.
- PLC / Modulo de expansión: Es el controlador del sistema de nivel de líquido, el cual recibe señales de los sensores de nivel para accionar el variador de frecuencia el cual regula la velocidad del motor.
- HMI: Este dispositivo nos permite la visualización de las medidas, escaladas por el PLC, en la parte frontal del panel de control.

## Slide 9

Pasos para la Puesta en marcha del Sistema

1

Energizar al sistema mediante su cable conector a 220 VAC.

Activar el interruptor principal, ubicado en el costado derecho de la planta.

Una vez energizado la planta se observa que tanto el dosificador como el controlador de temperatura están ya activos.

Activar los tres térmicos ubicados dentro del panel de control donde:

Térmicos de activación del sistema
(ubicados dentro del panel de control)

Interruptor principal de la planta
ubicado al costado derecho de la planta

2

3

4

BR1: Térmico encargado de la energización y activación del PLC
BR2: Térmico encargado de la energización de la fuente de alimentación y de los sensores que dependan de esta.
BR3: Térmico encargado de la energización del variador de frecuencia.

## ESQUEMA P&ID

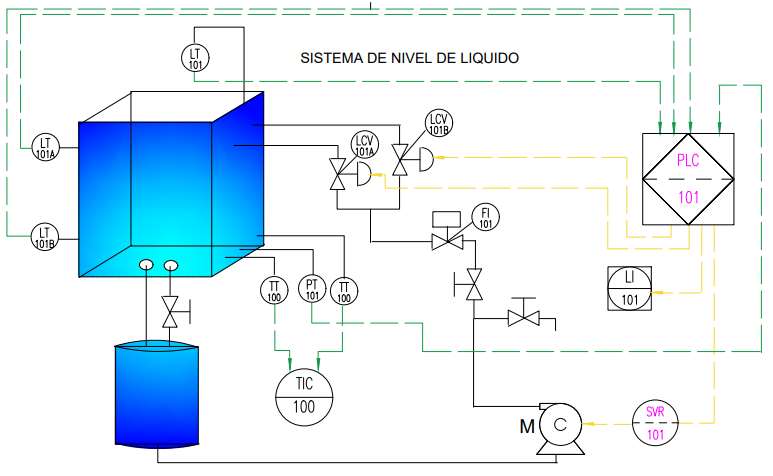
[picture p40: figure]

## DIAGRAMA ELÉCTRICO (SENSORES Y ACTUADORES)

## DIAGRAMA ELÉCTRICO (CONEXIÓN A LA REGLETA DEL PANEL)

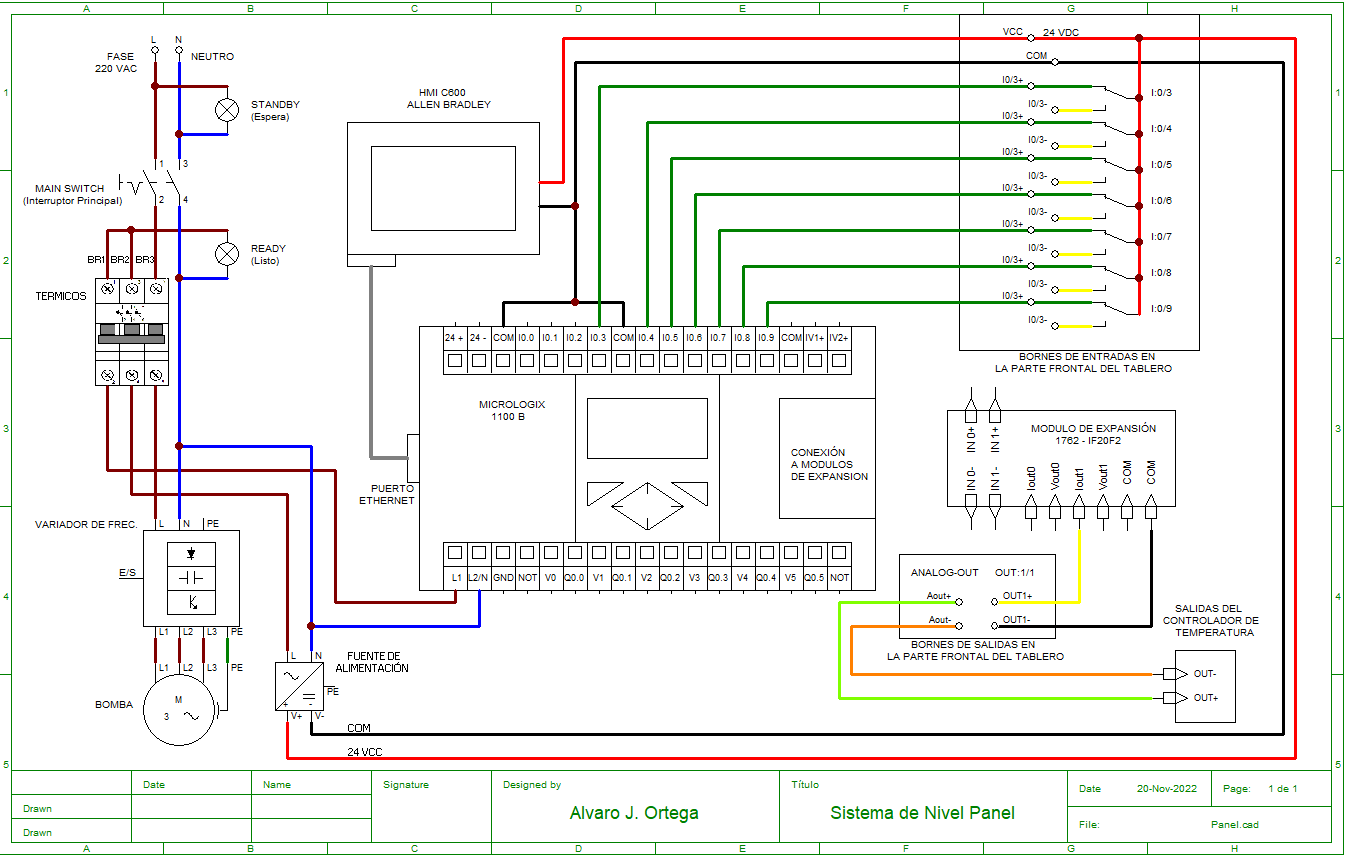
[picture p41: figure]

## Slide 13

INSTRUMENTACIÓN

## MULTIMETRO

En la mayoría de los casos se utilizara una instrumentación específica, uso únicamente un multímetro, para medir tensiones (Sensores de Temperatura y Vibratorios), corrientes (Sensores de presión, ultrasonido) y resistencia (Bomba).

## VARIADOR DE FRECUENCIA

El variador de frecuencia será utilizado como instrumento de medida de frecuencia, tensión y corriente.

## DOSIFICADOR

Se tendrá que calibrar el dosificador para ser utilizado como instrumento para medir el caudal.


## CAUDALIMETRO

Lectura del caudal de salida

Caudalimetro implementado al caudal de salida del sistema

El caudalimetro fue utilizado como instrumento de medida del caudal de salida de la planta necesario para la obtención de la función de transferencia del sistema.
El instrumento de medición tiene una capacidad máxima de 30 L/min

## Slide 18

SENSORES Y ACTUADORES

## MOTOR CENTRIFUGO (BOMBA)

El motor (Centrífugo Pentax CMT-100) es el transductor encargado de bombear el agua mediante la transformación de energía eléctrica a energía mecánica (rotacional) del tanque inferior hacia el superior. Las imágenes siguientes describen al mismo:


La conexión de este motor centrifugo es de configuración delta.

## VARIADOR DE FRECUENCIA

El variador de frecuencia regula la velocidad de motores eléctricos para que la electricidad que llega al motor se ajuste a la demanda real de la aplicación.
La conexión que se realizó en la planta es de una alimentación de 200-240V Monofásico y una salida al motor de 240 VAC Trifásico.

Posee la siguiente cantidad de entradas y salidas
- 5 entradas digitales (dos programables).
- 1 entrada analógica 0 a 10 VDC
- 1 entrada analógica 4 a 20 mA.
- 1 salida digital tipo relé

Ubicación del variador de frecuencia

## ELECTROVALVULAS

El sistema cuenta con dos electroválvulas “Burkert Type 6211” de tipo solenoide, los cuales permiten el paso del líquido para el llenado del tanque superior, estas electroválvulas son normalmente cerradas.
El control de activación se lo hace por medio de suministrar una tensión alterna de 230 V a una frecuencia de 50 o 60 Hz. En Las especificaciones se ve también la presión que este puede tolerar, siendo estas desde 0.5 a 10 [bar].


Especificaciones del producto

## DOSIFICACOR

El dosificador Burkert 8035 cumple la función de controlar y medir el volumen de líquido proporcionado al sistema, además nos brinda información del caudal de líquido que pasa a través de las tuberías

El módulo electrónico de control 8035 Batch utiliza una tensión de alimentación de 115/230 VCA y cuenta con 2 relés para realizar la dosificación.
El dosificador 8035 cuenta con 3 tipos de dosificación:
- Dosificación en modo manual
- Dosificación en modo automático
- Dosificación manual y automática


## MODOS DE FUNCIONAMIENTO DEL DOSIFICADOR

El dosificador burkert tiene 3 modos de funcionamiento:
- Modo de visualización
- Modo de calibración
- Modo de pruebas
Estos se acceden mediante los botones de navegación

## SENSOR DE ULTRASONIDO

El sensor de ultrasonido Allen modelo 873P-DCAC1S-D5 es un sensor ultrasónico programable ideal para medir la altura del nivel de líquido, tiene un rango de medición de 150 a 1500 mm.

El sensor cuenta con 5 pines los cuales 2 son para alimentación de 19 a 30 VDC, 2 de la salida discreta P1 y P2, y 1 de la salida analógica de corriente entre 4 a 20 mA.

Ubicación del sensor

## PROGRAMACIÓN DEL SENSOR DE ULTRASONIDO


La programación se lo realiza con el botón de configuración que se encuentra en la parte superior del sensor, eligiendo los puntos P1 y P2, también cuenta con 3 led’s indicadores 2 amarillos que corresponden a P1 y P2, y 1 led verde para indicar si un objeto está presente en el rango del sensor.

## SENSOR VIBRATORIO

Los interruptores de nivel, al igual que los sensores de nivel, son instrumentos de medición utilizados principalmente para detectar el nivel de llenado de productos almacenados en tanques, silos y otros depósitos de almacenamiento.

Al detectar la alteración de amplitud y de frecuencia de las vibraciones, el interruptor cambia de estado y esto es visible gracias a los indicadores lumínicos que tiene incorporado (luz verde y roja). En la modelo del sensor usado se cuenta con 4 clavijas, 2 corresponden a la alimentación, una salida digital de 0V a 24VCC y una tierra.

## SENSOR DE PRESIÓN

Los transductores de presión capacitivos son medidores que se basan en la utilización de un elemento elástico cuya deformación, proporcional a la diferencia de presión entre ambos lados de ese elemento elástico, se convierte en una señal eléctrica.

El sensor de presión cerabar T-PMC131 es un sensor capacitivo ideal para medir presión absoluta o relativa, tiene un rango de medición de 0 a 200 mbar con una presión máxima de trabajo de 3.3 bar y cuenta con protección IP65. Cuenta únicamente con 2 hilos conectores los cuales alimentan al sensor con 24 VCC y de respuesta este proporciona una corriente entre 4 a 20 mA por el mismo cable conductor.


## SENSORES DE TEMPERATURA

El sistema cuenta con 2 tipos de sensores las cuales son la Termocupla TD12 y el sensor de temperatura RTD OMNIGRAND T TST487. Estos sensores se ubican en la parte trasera del sistema y se conectan al controlador de temperatura.


## SENSOR DE TEMPERATURA TC

Este sensor de tipo J Hierro y Constantán(aleación de cobre y niquel), tiene un rango de trabajo de -40 C° a 750 °C es apto para zonas con peligro de explosión, su máxima presión de proceso a 20 °C es de 40 bar.

Una termocupla se hace con dos alambres de distinto material unidos en un extremo. Al aplicar temperatura en la unión de los metales se genera un voltaje muy pequeño del orden de los milivolts el cual aumenta con la temperatura.

## SENSOR DE TEMPERATURA RTD

Este sensor RTD es un tipo Pt100 las cuales deben su nombre al hecho de estar fabricados de platino (Pt) y presentar una resistencia de 100ohms respectivamente a 0° C.
Tiene la conexión de cuatro hilos, lo cual hace al sensor más preciso. Tiene un rango de temperatura de -50°C a + 300°C, máxima presión de proceso (estática): 20 °C: 20 bar.

Los RTD son sensores de temperatura resistivos. En ellos se aprovecha el efecto que tiene la temperatura en la conducción de los electrones para que, ante un aumento de temperatura, haya un aumento de la resistencia eléctrica que presentan.

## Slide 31

CARACTERIZACION DE SENSORES Y ACTUADORES
Pruebas en Laboratorio

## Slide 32

MOTOR BOMBA

Los valores de frecuencia y de voltaje fueron obtenidos directamente del variador de frecuencia, ya que este cuenta con la opción de visualización de frecuencia y su correspondiente valor en voltaje alterno a dicha frecuencia elegida o regulada, el cual va hacia el motor bomba.
En la gráfica se observa un comportamiento muy próximo a ser lineal al compararlo con línea de tendencia lineal, lo cual nos indica que las variaciones de frecuencia corresponden de forma muy próxima a las de tensión, observando también el correcto escalamiento que presentan ambas variables, donde un valor mínimo de frecuencia de 0 Hz involucra una tensión de 0 VAC y un valor máximo de frecuencia de 50 Hz significa un valor de 230 VAC.

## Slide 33

DOSIFICADOR


En la prueba de laboratorio, con ayuda del variador de frecuencia, se obtuvo una relación lineal entre el voltaje y el caudal esto para tener información del caudal que es capaz de suministrar la bomba en base al voltaje de funcionamiento del mismo.
Los valores de voltaje fueron obtenidos directamente del variador de frecuencia, ya que este cuenta con la visualización de voltaje al variar y regular la frecuencia. Los valores de caudal fueron obtenidos del dosificador, observando la variación del mismo ante la variación de voltaje que le llega al motor bomba.

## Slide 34

SENSOR DE ULTRASONIDO

Los datos de altura fueron tomados visualmente de una cinta métrica colocada al costado del tanque superior y los datos de corriente (correspondiente a una altura) fueron medidos con un multímetro.
Esta prueba es realizada con el fin de obtener el equivalente de la señal analógica (corriente) con respecto a una altura cualquiera, que por motivos de la gráfica fueron dándose de 5 en 5 de forma ascendente.
Estos datos son de mucha ayuda para la adaptación de señales que se realiza al presente sensor.

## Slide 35

SENSOR DE PRESION

Los datos de altura fueron tomados visualmente de una cinta métrica colocada al costado del tanque superior y los datos de corriente (correspondiente a una altura) fueron medidos con un multímetro.
Esta prueba es realizada con el fin de obtener el equivalente de la señal analógica (corriente) con respecto a una altura cualquiera, que por motivos de la gráfica fueron dándose de 5 en 5 de forma ascendente.
Estos datos son de mucha ayuda para la adaptación de señales que se realiza al presente sensor.

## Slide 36

SENSOR DE TEMPERATURA TC


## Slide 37

SENSOR DE TEMPERATURA RTD

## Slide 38

CONTROLADORES

## PLC MICROLOGIX 1100

El controlador de la serie MicroLogix 1100 cuenta con 10 entradas de 24 VDC y 6 salidas de relé, un puerto Ethernet/IP para comunicaciones con HMI y cuenta con 1 modulo de expansión 1762-IF20F2 el cual es un módulo analógico de voltaje/corriente con combinación de 2 canales de entrada y 2 canales de salida.

Se ubica en la parte interior del panel de control

Los 2 canales de entrada se utilizarán para las lecturas del sensor ultrasónico y el sensor de presión, mientras que se ocupara un canal de salida (en configuración de corriente) para realizar el control a 2 hilos del variador de frecuencia.

## CONTROLADOR DE TEMPERATURA

Este controlador tiene la característica de aceptar distintos modelos de sensores de temperatura todas las termocuplas del mercado y RTD's. Tiene una frecuencia operativa de 50-60 Hz y una alimentación de 220 VAC (Para evitar dañar al usuario tiene un protector para dedos que evita electrocutarnos).


Se ubica en la parte frontal y trasera de la puerta del panel de control

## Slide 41

ADAPTACION DE SEÑALES

## ¿QUÉ ES ADAPTACION DE SEÑALES?

La adaptación de señales es la manipulación de una señal analógica de tal manera que cumpla con los requisitos de la siguiente etapa para su procesamiento posterior.

En la imagen se observa que el PLC recepción las medidas tomadas por el sensor y las procesa conjuntamente con la referencia, pero debe realizar una adaptación de señales para accionar el actuador

## ADAPTACIÓN DE SEÑALES POR SOFTWARE

Para realizar la adaptación de señales usaremos la función SCP en la programación en Ladder en el software rslogix micro english.

Dependiendo del tipo de sensor que se utilizará se tendrá una señal analógica especifica y dependiendo al tipo de configuración de la señal analógica se tendrá 2 maneras de generarla (para control PID, o proporcional).

En la práctica se deberá de utilizar la configuración para 4mA – 20mA (Min: 3277 - Max:16384) pues se utilizará para acondicionar la señal de salida del sensor de presión y de ultrasonido.

## CONCLUSIONES

- Durante el proceso se desarrollaron habilidades y destrezas sobre la instrumentación con el fin de poder reconocer, adaptar y caracterizar sensores y/o actuadores, los cuales abundan en el área profesional y son de vital importancia poder conocerlos y manipularlos.
- Para el proceso se utilizó el estándar de la norma ISA para describir el diagrama de tuberías P&ID, obteniendo así el conocimiento sobre dicho estándar y reglas que este cumple.
- También se logró identificar que el sistema tiene la función de realizar el control de nivel de líquido utilizando los sensores de nivel y el motor como actuador. Adicionalmente el sistema es aprovechado para realizar la medición de presión, temperatura y caudal para brindar información al usuario.
- Además, se consiguió caracterizar los elementos que componen al sistema (sensores y actuadores) de forma tal de tener información adecuada y necesaria para el funcionamiento del sistema e implementar un futuro control de nivel.
- Finalmente, se pudo evidenciar que la mayoría de los sensores que conforman el sistema requieren una adaptación de señales por software.

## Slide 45

DISEÑO DEL CONTROLADOR

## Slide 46

OBJETIVOS
- Diseñar un controlador en el espacio de estados para el sistema de control de nivel.
- Desarrollo de habilidades y destrezas para la interacción con el PLC real, teniendo en cuenta los factores de escalamiento e introducción de los valores hallados
- Visualizar y monitorear el funcionamiento del sistema mediante el HMI

## FUNCIÓN DE TRANSFERENCIA DEL SISTEMA

## FUNCIÓN DE TRANSFERENCIA DEL SISTEMA (continuación)


Como se observa, el sistema alcanza el máximo nivel del tanque, 50 cm, en aproximadamente 14.9 min. Con esto en mente los requerimientos que nos planteamos serán que el sistema tenga un tiempo de asentamiento de 4 min y un máximo sobrepaso de 1% (esto porque el sistema es muy lento y el sobrepaso no será notorio).

## DISEÑO DE CONTROLADOR AÑADIENDO UN INTEGRADOR

Servosistema tipo 1 (planta sin integrador)

## DISEÑO DE CONTROLADOR AÑADIENDO UN INTEGRADOR (Requerimientos)

## DISEÑO DE CONTROLADOR AÑADIENDO UN INTEGRADOR (Diseño de K por Akerman)

## RESPUESTA DEL SISTEMA A LAZO CERRADO

Respuesta del sistema para una entrada de referencia de 30 cm

## ELECCION DEL PERIODO DE MUESTREO


## DISEÑO DEL CONTROLADOR DEL SISTEMA DE 1er ORDEN

Para la implementación del controlador del servosistema se pensó en utilizar el bloque PID, que nos proporciona el PLC micrologix 1100, para agregar la acción integral con un control PI; pero debido a que el escalamiento de salida (0 a 16383) nos impedían relacionar la señal de control del controlador PI con la ganancia de realimentación de estados K para generar una señal de control u(t).
Es por este motivo que se opto por un diseño de un controlador por realimentación de estados para el sistema de primer orden,

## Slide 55

DISEÑO DEL CONTROLADOR DEL SISTEMA DE 1er ORDEN
(Discreto)


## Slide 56

DISEÑO DEL CONTROLADOR DEL SISTEMA DE 1er ORDEN
(Continuo)

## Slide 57

COMPARACION DE LAS RESPUESTAS EN CONTINUA Y DISCRETA


## CONTRASTE CON LA ETAPA ANALÍTICA

## IMPLEMENTACION DEL CONTROLADOR


## DATOS DE LABORATORIO

Realizando pruebas en laboratorio se verifico que a partir de 10 [Hz] recién se empezaba a llenar el tanque superior, es por eso que se realizara una regresión lineal sin tomar en cuenta los recuadros celestes. Y de la misma manera como se tomaron lecturas cuando la red de cañerías no estaba llena de agua, la primera medida del dosificador es descartada.

Es necesario el uso de los datos obtenidos en laboratorio para relacionar caudal a frecuencia y con ayuda del PLC generaremos una salida analogica de 4 - 20 mA (con resolución de 15 bits).
Esta salida analógica será necesaria para realizar el control a 2 hilos del variador de frecuencia.

## LIMITACIONES


Simulación realizada en Simulink

## DISEÑO DEL CONTROLADOR EN LADDER


## REDISEÑO DEL SISTEMA

Para evitar saturar el actuador para un tiempo de asentamiento excesivamente pequeño, se puede rediseñar el sistema para que en un tiempo mas elevado (12 min) se alcance la referencia.

## CONSIDERACIONES PARA LA IMPLEMENTACION

El controlador diseñado no considera que puede existir una obstrucción que tape por completo o de manera parcial la salida de agua del tanque, el sistema sigue manteniendo un caudal de ingreso equivalente al caudal de salida constante de manera que a largo plazo el incremento de nivel por encima de la referencia es inevitable.
Para remediar esto, se diseño un sistema de alarma que permita cortar el suministro de agua al tanque superior si se ha sobrepasado un cierto margen de protección (2cm encima de la referencia).


## DISEÑO DE LA INTERFAZ PARA EL HMI

## CONCLUSIONES

- Se diseño un controlador de realimentación de estados para un servosistema para incrementar la cantidad de estados (con un integrador), sin embargo por la dificultad de hallar una relación para la salida del bloque PID para la relación con la matriz de ganancia de realimentación, se lo descarto y se realizo el diseño de un controlador por realimentación de estados con la planta original de primer orden. (Los resultados obtenidos fueron satisfactorios, consiguiendo el control del sistema)
- Mediante el diseño de un programa en LADDER se consiguió ejecutar la acción de control sobre el actuador (variador de frecuencia), consiguiendo conocimiento, habilidades y destrezas para la interacción con el PLC real.
- Se realizo una interfaz para la comunicación de las variables de proceso con un esquema funcional para la visualización y monitoreo del sistema. Sin embargo, no se logro cargar el archivo al HMI por dificultades en la vinculación (software del hmi)

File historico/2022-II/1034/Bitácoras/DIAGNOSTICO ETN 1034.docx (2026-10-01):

Universidad “Mayor de San Andrés”

FACULTAD DE INGENIERIA


DIAGNOSTICO SISTEMA DE

NIVEL DE LIQUIDO.

Integrantes: Univ. Ortega Quispe Alvaro Jhonny

Univ. Tiñini Vallejos Milton Rodrigo

Carrera: Ing. Electrónica

Materia: ETN 1034

Docente: Ing. Jorge A. Nava A.

Auxiliares: Univ. Huarachi M. Rhem J.

Univ. Huanca Mita Miguel

Fecha: 13/12/2022

La Paz – Bolivia

Descripción del estado en que fue encontrado la plataforma de laboratorio “SISTEMA DE NIVEL DE LIQUIDO”

Vista frontal de la Planta.


Vista trasera e inferior de la Planta


DESCRIPCIÓN DEL ESTADO FÍSICO Y FUNCIONAL

- La planta inicialmente fue encontrada en un estado “visual” aceptable, donde no se observaba daños, grietas, o ausencia de algún dispositivo o equipo. Físicamente la planta estaba en buenas condiciones, con la excepción de suciedad y polvo que la recubrían, las cuales fueron subsanadas con una limpieza general tanto de tuberías como de los tanques inferior y superior, como el armazón del sistema en general.
- En cuanto a su estado funcional, la planta encendía con normalidad al suministrarle la energía necesaria para su activación, no se observaron alarmas ni indicadores de un mal funcionamiento más que notar visualmente la lectura de “error” del controlador de temperatura, el cual será descrito más adelante.

ELECTROVALVULAS


- El par de electroválvulas con que cuenta el sistema se encontraban en condiciones aceptables, no se observaron grietas ni algún otro deterior más que notar la conexión ausente del tercer cable (color verde) de puesta a tierra, el cual solo colgaba.
- Funcionalmente ambas electroválvulas no se encontraban en buen estado ya que no se accionaban, solo respondían con una confirmación “audible” de su activación, pero el líquido continuaba circulando permanentemente. Es por ello que verificando su manual y hoja de características se encontró su posible falla y se procedió a desarmarlas para su limpieza y correcto aseguramiento del resorte que es intermediario para la apertura y cierre de la electroválvula al momento de efectuarse el campo magnético que provoca dicho cambio de estado. Y de este modo se corrigió el estado de ambas electroválvulas.

Electroválvulas del sistema

MOTOR BOMBA


Motor bombas del sistema

- Del mismo modo dicho actuador se encontraba “visualmente” en buenas condiciones, con su cableado conectado correctamente y empalme hacia las tuberías bien aseguradas.
- Funcionalmente el motor bomba respondió adecuadamente sin presentar mal estar o ruido audible que demostrara un mal funcionamiento. Sin embargo, cabe mencionar el esfuerzo que este realiza cuando no se abren las electroválvulas para la correcta circulación del líquido entre los tanques inferior y superior, lo que puede llegar a provocar el “ahogamiento” de la bomba.

SENSOR DE PRESION

- El sensor de presión de la planta físicamente no presento inconvenientes ni rastros de maltrato o mal estado, el par de cables que presenta para su alimentación y respuesta de medición se encontraba correctamente instalado.
- Funcionalmente las pruebas realizadas con el sensor dieron a conocer que este presenta un error de punto cero (pues comienza la medición en 3.9mA y no en 4mA), esto se puede solucionar realizando la calibración respectiva o mediante la adaptación de señales por software.


Sensor de presión del sistema

DOSIFICADOR


- En cuanto al dosificador, se lo encontró visualmente con su carcasa en buen estado y sin daños a simple vista, sin embargo, Había muchas conexiones no realizadas, donde se observó también la ausencia del conexionado de la electroválvula que esta presenta al PLC.
- Funcionalmente las pruebas realizadas verificaron lo mencionado en el diagnostico físico, donde prácticamente por las conexiones no realizadas, el uso que brinda el dosificador es solo de un instrumento de medición de caudal y volumen, en este sentido no se encontraron errores.

El modo de control automático de caudal que brinda se ve directamente afectada por la ausencia de conexión tanto del cableado de los relés como de la electroválvula ya mencionada.

Dosificador del sistema

SENSORES DE TEMPERATURA


Sensor “TC” y Sensor “RTD” de temperatura del sistema

- En cuanto a los sensores de temperatura, ambos se encontraban en buen estado, no se encontraban conectados al controlador de temperatura, por lo que se procedió a conectarlos con ayuda de la cinta termoretráctil para su funcionamiento y visualización.
- Funcionalmente mediante pruebas realizadas se verifico la correcta medición de temperatura que estos presentan.

CONTROLADOR DE TEMPERATURA


- La maqueta de nivel de líquido cuenta en la parte frontal del tablero con conectores hembra del tipo banana para realizar la conexión al controlador, pero no se contaba con conectores del tipo banana-banana; es por esta razón que se adquirieron 3 conectores banana-banana para poder utilizar el controlador de temperatura, por el momento, como un indicador
- Funcionalmente el controlador responde a las medidas de temperatura que brindan ambos sensores, pudiendo también escoger cuál de ellos visualizar.

SENSOR DE ULTRASONIDO

- El sensor fue encontrado en buenas condiciones, ya ubicado por encima del tanque superior para realizar medidas verticalmente, donde la conexión de su cableado hacia el PLC (específicamente al módulo de expansión) estaba realizado correctamente, así también la conexión de alimentación al mismo.
- El sensor brinda medidas de acuerdo como se lo programe, verificando además que los tiempos para la programación del mismo funcionan de forma correcta y se puede establecer los límites superior e inferior de medición. Y mediante una escala realizada manualmente al costado del armazón del sistema se comprobó (previo escalamiento del sensor) que las medidas dadas por el sensor eran correctas

Sensor de ultrasonido del sistema

SENSORS VIBRATORIOS


- Ubicados en la parte lateral izquierda del tanque superior, los sensores vibratorios de nivel fueron encontrados físicamente en buen estado, sin daño alguno con su respectivo cableado hacia el PLC y su cableado de alimentación.
- En cuanto a su funcionamiento se observó que el sensor produce un sonido agudo, lo que es completamente normal. Los indicadores LED propios del sensor se encontraban operando de forma correcta y esperada.

Se verifico así que su funcionamiento era el correcto, con la única observación que su salida de información digital es de 0 a 22,1 V, lo que teóricamente según su alimentación debería de ser 0 a 24V.


Sensores Vibratorios del sistema

CONTROLADOR LOGICO PROGRAMABLE “PLC”

Y SU MODULO DE EXPANSIÓN.

- El PLC y su módulo de expansión visualmente presentaban buenas condiciones, observando una correcta conexión de sus entradas y salidas, así como el encendido y activación de forma normal al suministrarles energía.
- Funcionalmente en la vinculación entre PLC y computador para cargar el programa respectivo se encontró con que el PLC no presentaba una dirección IP, la cual fue asignada para poder vincular los equipos mencionados. En cuanto al módulo de expansión este presentaba un correcto funcionamiento, recibiendo información del sensor de presión y de ultrasonido para el tratamiento de la señal de corriente (analógica)


PLC y módulo de expansión del sistema

Variador de Frecuencia


Variador de frecuencia del sistema

- Físicamente el variador de frecuencia se encontraba en buen estado, verificando el correcto conexionado entre este y el motor bomba y su alimentación para su activación.
- En cuanto a su funcionamiento este cumplía con su trabajo. Sin embargo, en las pruebas realizadas para su control se encontró con la mala conexión para el uso de este en modo de programación por corriente, notando que el par de cables para dicho modo estaba conectado inversamente (cables de corriente y común)

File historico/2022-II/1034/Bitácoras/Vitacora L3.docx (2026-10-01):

Universidad “Mayor de San Andrés”

FACULTAD DE INGENIERIA

CARACTERIZACION DEL SISTEMA DE NIVEL DE LIQUIDO.

Integrantes: Univ. Ortega Quispe Alvaro Jhonny

Univ. Tiñini Vallejos Milton Rodrigo

Carrera: Ing. Electrónica

Materia: ETN 1034

Docente: Ing. Jorge A. Nava A.

Auxiliares: Univ. Huarachi M. Rhem J.

Univ. Huanca Mita Miguel

Fecha: 13/12/2022

La Paz – Bolivia

TABLA DE CONTENIDO

1. OBJETIVOS 3

2. PROCESO DE NIVEL DE LIQUIDO 3

2.1. Estructura del sistema: 3

2.2. Componentes del sistema: 3

2.3. Funcionamiento 3

2.4. Puesta en marcha del Sistema 4

2.5. Esquema P&ID 6

2.6. Función de transferencia 7

2.7. Esquema eléctrico 8

3. INSTRUMENTACIÓN 10

4. SENSORES Y ACTUADORES 11

4.1. MOTOR CENTRÍFUGO 11

4.2. VARIADOR DE FRECUENCIA 13

4.3. ELECTROVÁLVULAS 14

4.4. DOSIFICADOR 16

4.5. SENSOR DE ULTRASONIDO 18

4.6. SENSORES VIBRATORIOS 20

4.7. SENSOR DE PRESIÓN 21

4.8. SENSORES DE TEMPERATURA 23

4.8.1. Termocupla (TC) 23

4.8.2. Resistencia Variable (RTD) 24

5. CARACTERIZACION DE SENSORES Y ACTUADORES 25

6. CONTROLADORES 29

6.1. CONTROLADOR LÓGICO PROGRAMABLE MICROLOGIX 1100 29

6.2. CONTROLADOR DE TEMPERATURA ALLEN BRADLEY 900-TC16 30

7. ADAPTACION DE SEÑALES 33

8. OBSERVACIONES, RECOMENDACIONES y CONCLUSIONES 34

9. BIBLIOGRAFIA (DATASHEET O MANUALES) 35

1. OBJETIVOS
- Desarrollar habilidades y destrezas en la instrumentación de laboratorio y proceso.
- Representar al proceso en su totalidad utilizando la normativa ISA (P&ID)
- Identificar y Caracterizar los elementos que componen al sistema (sensores y actuadores)
- Identificar y Realizar la adaptación de señales para aquellos transductores en los que sea necesario
2. PROCESO DE NIVEL DE LIQUIDO
2.1. Estructura del sistema:


- Estructura metálica color azul
- Dos tanques de almacenamiento de agua
- Soporte para sensores y tablero de control
- Tuberías de ½ y ¾
2.2. Componentes del sistema:
- 2 sensores vibratorios
- 2 electroválvulas
- Flujómetro digital (Dosificador)
- Sensor de presión
- Sensor de temperatura TC (Termocupla)
- Sensor de temperatura RTD (Resistivo)
- Controlador de temperatura
- motor trifásico de 1HP
- Variador de frecuencia
- Sensor de Ultrasonido
- PLC (Micrologix 1100)
- 1 módulo de expansión (para PLC)
- Fuente de alimentación de 24V
- Pantalla de 6 pulgadas touch Panelview C600
2.3. Funcionamiento
- Sensores vibratorios: Es utilizado para la detección de nivel alto y bajo del líquido en el tanque.
- Sensor ultrasónico: Es utilizado para la medición de la altura del nivel de líquido del depósito.
- Sensor de presión: Es utilizado para la medición de presión relativa en el tanque y también se puede usar para medir la altura del líquido teniendo como referencia la posición de este sensor.
- Sensores de temperatura TC/RTD: Están conectados al controlador de temperatura para dar mediciones de la temperatura del líquido.
- Controlador de temperatura: Este controlador es utilizado como un indicador de temperatura, sin aprovechar su capacidad de realizar una acción de control.
- Flujómetro (Dosificador): Utilizado para la medición del caudal y volumen del líquido.
- Electroválvulas: Permiten el cierre o paso del líquido por la red de cañerías.
- Variador de frecuencia: Permite regular la velocidad de giro del motor, mediante la variación de frecuencia del mismo, de manera que se pueda bombear el líquido del tanque inferior al superior.
- Motor. (bomba) Actuador encargado de llevar el líquido del tanque inferior al tanque superior para el llenado y control del mismo.
- PLC / Modulo de expansión: Es el controlador del sistema de nivel de líquido, el cual recibe señales de los sensores de nivel para accionar el variador de frecuencia el cual regula la velocidad del motor.
- HMI: Este dispositivo nos permite la visualización de las medidas, escaladas por el PLC, en la parte frontal del panel de control.
2.4. Puesta en marcha del Sistema

Para la puesta en funcionamiento y energización del sistema se deben seguir los siguientes pasos:

- Energizar al sistema mediante su cable conector a 220 VAC.
- Activar el interruptor principal, ubicado en el costado derecho de la planta.
- Una vez energizado la planta se observa que tanto el dosificador como el controlador de temperatura están ya activos. Sin embargo, para completar con la puesta en funcionamiento y energización de la planta se debe activar los tres térmicos ubicados dentro del panel de control donde:
1) BR1: Térmico encargado de la energización y activación del PLC
2) BR2: Térmico encargado de la energización de la fuente de alimentación y de los sensores que dependan de esta.
3) BR3: Térmico encargado de la energización del variador de frecuencia.

BR1

BR2

BR3

Interruptor principal de la planta

(ubicado al costado derecho de la planta)

Térmicos de activación del sistema

(ubicados dentro del panel de control)

A continuación, se muestra y presenta al sistema como tal, mostrando visualmente los dispositivos, sensores, actuadores, controladores e indicadores que conforman al mismo.

En la figura se muestra una vista frontal del sistema, el panel de controla por delante y por dentro, además de los elementos que la conforman.


En la figura se muestra una vista inferior donde se encuentra el motor bomba de la planta.

También se muestra la vista trasera del sistema, donde están ubicados varios de los sensores descritos anteriormente, además que se los señala por colores de que elementos o dispositivos se trata. Y finalmente se muestra la ubicación de los sensores de nivel al costado izquierdo y parte superior del tanque que almacena el líquido.


2.5. Esquema P&ID

El diagrama o esquema de tuberías PI&D que especifica el sistema de nivel de líquido es realizado con ayuda de la herramienta “AutoCAD Electrical”, donde la simbología, numeración, especificación de líneas, conexiones y lazos de control se realizó en base a la norma ISA.


En la siguiente figura se especifica las señales de instrumentación, la función de cada instrumento, las letras identificadoras y la simbología usada en la representación del sistema


Simbología de instrumentación utilizada

2.6. Función de transferencia

El esquema presentado a continuación corresponde a un sistema básico de nivel de líquido:


Donde:

- C=Capacitancia del tanque
- R=Resistencia al paso del liquido
- q_i (t)=Caudal de entrada
- q_0 (t)=Caudal de salida
- h(t)=Altura del liquido

Para encontrar una función de transferencia que represente al sistema debemos utilizar ecuaciones diferenciales ordinarias:

C (dh)/(dt)=q_i (t)-q_0 (t)…(1) q_0 (t)=(h(t))/R…(2)

Utilizando la transformada de Laplace conseguimos la función de transferencia:

C sH(s)=Q_i (s)-Q_0 (s)…(1^(') ) Q_0 (s)=(H(s))/R…(2')

Reemplazamos (2’) en (1’)

C sH(s)=Q_i (s)-(H(s))/R → H(s)(Cs+1/R)=Q_i (s) → (H(s))/(Q_i (s))=(1/C)/(s+1/(CR))

Como se puede observar el sistema es de primer orden estable, lineal y estacionario.

2.7. Esquema eléctrico


Diagrama eléctrico de conexión al panel frontal


Diagrama eléctrico de circuito de control del PLC y sus salidas hacia electroválvulas y baliza; entradas del sensor de ultrasonido, de presión a las entradas al módulo de expansión analógica y la conexión del flujómetro

3. INSTRUMENTACIÓN

En la mayoría de los casos se utilizará una instrumentación específica, uso únicamente un multímetro, para medir tensiones (Sensores de Temperatura y Vibratorios), corrientes (Sensores de presión, ultrasonido) y resistencia (Bomba).

Lectura de la corriente que proporciona el controlador de temperatura

Lectura del voltaje

El variador de frecuencia será utilizado como instrumento de medida de frecuencia, tensión y corriente.

Adicionalmente, se tendrá que calibrar el dosificador para ser utilizado como instrumento para medir el caudal.


Visualizar Frecuencia

Visualizar Corriente

Visualizar Tensión

4. SENSORES Y ACTUADORES
  4.1. MOTOR CENTRÍFUGO

El motor (Centrífugo Pentax CMT-100) es el transductor encargado de bombear el agua mediante la transformación de energía eléctrica a energía mecánica (rotacional) del tanque inferior hacia el superior. Las imágenes siguientes describen al mismo:

Motor Centrifugo Pentax Water pumps CMT 100/00

Ubicación de la bomba

Placa de la bomba

Para el sistema el motor es usado para bombear el agua hacia el tanque superior y realimentar la planta. Es por ello que las especificaciones necesarias fueron: la altura y el caudal de bombeo del líquido, la frecuencia del lugar donde trabajara y también potencia, voltaje y corriente necesaria para realizar el proceso de bombeo. Es un motor de 2 polos de inducción (número de juegos de bobinados electromagnéticos de tres vías que tiene un motor), los cuales influye en la velocidad del motor que como se observa es de 2800 [rpm].

Para una mejor visualización se presenta a continuación las características que presenta el motor:


H < 2m

Con la conexión de las tuberías como se ve en la imagen, no se excede ni los 2m de altura y el caudal es regulado con un variador de frecuencia, Con lo que las especificaciones, potencia, altura y caudal son suficientes para esta planta, además la tensión, corriente y frecuencia son adecuados para nuestra región

Medición de las resistencias de los devanados del motor: para demostrar que los bobinados del mismo están actuando de forma correcta (verificar que no se hayan partido o juntado)

Carga equilibrada: significa que las bobinas tienen misma resistencia, lo que implica misma longitud y misma inductancia, lo que es necesario para un motor trifásico.


Cabe señalar el tipo de conexión del motor, donde se puede verificar en la figura que el tipo de conexión es “delta” (chapas conectadas en forma paralela en la bornera de salida de las 3 bobinas), donde se puede mencionar que en la conexión en estrella la cantidad de aislamiento es baja y nos proporciona menos torque en comparación con la conexión delta. En la conexión delta la cantidad de aislamiento es elevada, debido a las corrientes más elevadas que circulan por las bobinas y nos proporciona un torque más elevado.

Foto tomada del motor del sistema

El valor de resistencia obtenido con ayuda de un multímetro es:

R=6.4[Ω]

Verificando también que las tres bobinas presentan la misma resistencia especificada.

Para mayor información acerca del motor revisar “Hoja de datos motor trifásico CMT 100/00” (https://www.afripumps.co.za/images/stories/virtuemart/pdfs/Pentax_CM_series.pdf)

CONEXION DEL MOTOR CON VARIADOR DE FRECUENCIA

Para mayor información sobre la conexión motor/variador de frecuencia, esta se puede obtener del esquema eléctrico correspondiente a dicha conexión, especificando por colores en los cables a qué tipo de conexión se refiere.

  4.2. VARIADOR DE FRECUENCIA

El variador de frecuencia regula la velocidad de motores eléctricos para que la electricidad que llega al motor se ajuste a la demanda real de la aplicación.

POWERFLEX 4M

Los variadores PowerFlex 4M es la solución más económica y compacta para control de velocidad que nos ofrece Allen Bradley.

Proporciona a los usuarios un potente control de velocidad del motor en un diseño compacto que ahorra espacio, es fácil de usar y proporcionan flexibilidad de aplicación, cableado de alimentación directa y facilidad de programación.

La conexión que se realizó en la planta es de una alimentación de 200-240V Monofásico y una salida al motor de 240 VAC Trifásico.

Los PowerFlex 4M poseen la siguiente cantidad de entradas y salidas:

- 5 entradas digitales (dos programables).
- 1 entrada analógica 0 a 10 VDC
- 1 entrada analógica 4 a 20 mA.
- 1 salida digital tipo relé, un polo doble tiro.

De las entradas mencionadas solo se utilizan las 2 entradas digitales (RUN y STOP) para realizar el arranque del motor con parámetros previamente ya programados, control a 3 hilos, y con la entrada analógica de 4 a 20 mA se puede realizar un control a 2 hilos pudiendo manejar el variador de manera remota.

Entradas y salidas del variador de frecuencia

Para mayor información revise el manual del variador de frecuencia powerflex 4M (https://drive.google.com/file/d/1-xUMAyj1BGngUbKiT9Q-8fwbbRxXZPqO/view?usp=sharing).

NOTAS

- Aprovechando la programación del tiempo de aceleración y desaceleración conjuntamente con las conexiones digitales para realizar stop y run, o las conexiones analógicas de 4 a 20 mA, se puede comenzar a utilizar el variador sin necesidad de un operador ya sea con un control a 2 o 3 hilos.
- Debido a la corriente que dispone el motor para arrancar (4 Amperios) no se puede ajustar la corriente máxima suministrada al motor pues este llega a consumir más de 4 Amperios en su máxima capacidad y esto provoca que los térmicos salten des energizando el motor y variador; por ello se recomienda no trabajar con la máxima capacidad del variador para evitar interrupciones en el suministro de energía.
  4.3. ELECTROVÁLVULAS

El sistema cuenta con dos electroválvulas “Burkert Type 6211” de tipo solenoide, los cuales permiten el paso del líquido para el llenado del tanque superior, estas electroválvulas son normalmente cerradas, es decir que ante la existencia de energía se abren, y se cierran cuando se quita la energía.

El tipo solenoide realiza la apertura y cierre de la válvula mediante la generación de un campo magnético, el cual contrae el embolo dentro de la válvula para que este pase de un estado de cierre a un estado de apertura e inversamente deja de generar el campo magnético para pasar de un estado de abierto a cerrado.

Las electroválvulas son de 2/2 vías, es decir que presenta solo dos estados (apertura y cierre).

Válvula 2/2 vías normalmente cerrada

En las especificaciones se puede observar las características de funcionamiento de esta, donde su control de activación se lo hace por medio de suministrar una tensión alterna de 230 v a una frecuencia de 50 o 60 Hz. En Las especificaciones se ve también la presión que este puede tolerar, siendo estas desde 0.5 a 10 [bar].


Tipo

Principio de funcionamiento

Orificio

material de sellado

Material de la carcasa

Número de identificación

Fabricante - código

Voltaje, frecuencia, consumo de energía.

Rosca de conexión, presión nominal

Placa de Características

Electroválvulas del sistema

POSIBLES FALLAS O INCONVENIENTES

Juego de bobinas

Juego de piezas de desgaste

La válvula no cambia. Causa posible:

• Cortocircuito o bobina interrumpida.

• Núcleo o área del núcleo sucia.

• Media presión fuera del rango de presión permitido.

La válvula no cierra. Causa posible:

• El espacio interno de la válvula está sucio.

• Pequeño orificio de control en el diafragma bloqueado.

• Diafragmas defectuosos.

NOTAS.

Las electroválvulas son energizadas con tensión alterna de 230 VAC, dicha energía es producto de la salida a relé del PLC. Sin embargo, por el transcurso del tiempo de estas inicialmente solo nos daban una confirmación audible de su activación, pero las electroválvulas se mantenían abiertas permanentemente. Es por ello que se las desmonto y procedió con la limpieza de las partes que la conforman, incluida su membrana de apertura y cierre, la cual estaba sucia. De este modo se consigue corregir su correcto funcionamiento.

Esto se debe a que las electroválvulas no fueron utilizadas por un largo tiempo consiguiendo que se deterioren (ensucien) o incluso se obstruyan los orificios que esta tiene.

Otro factor que se debe tomar en cuenta es el de no exceder su rango de presión permitida (0.5 a 10 bares), esto para no estropearla y mantener un ciclo de vida a largo plazo, además de que solo así se podrá observar y verificar su correcto funcionamiento.

CONEXIÓN DE ELECTROVALVULAS (para mayor información revisar el esquema eléctrico)


  4.4. DOSIFICADOR

El dosificador Burkert 8035 cumple la función de controlar y medir el volumen de líquido proporcionado al sistema, además nos brinda información del caudal de líquido que pasa a través de las tuberías. Todo esto gracias a un rodete que gira en proporción al fluido que pasa por la tubería.

El dosificador Burkert 8035 se instala en una tubería, en serie con una válvula. La unidad 8035 mide el caudal, calcula el volumen y actúa sobre la válvula según el programa seleccionado. El módulo electrónico de control 8035 Batch utiliza una tensión de alimentación de 115/230 VCA.

El dosificador 8035 cuenta con 3 tipos de dosificación:

- Dosificación en modo manual
- Dosificación en modo automático
- Dosificación manual y automática

FUNCIONAMIENTO

El dosificador burkert tiene 3 modos de funcionamiento:

- Modo de visualización
- Modo de calibración
- Modo de pruebas

El modo de visualización es el primero que se ve al entrar en funcionamiento el dosificador, tiene la utilidad de mostrarnos el volumen dosificado y el caudal de líquido. El modo de calibración tiene un menú donde puede configurarse los parámetros del dosificador y el modo de pruebas nos sirve para probar el funcionamiento de los relés y comprobar la configuración de las entradas binarias para el modo de dosificación automática.

Validación del menú o el parámetro elegido

Desplazamiento por los menús o selección de un digito para modificarlo

Desplazamiento por los menús o incremento de un valor

Estados de los relés 1 y 2

Para observar el manejo del dosificador ingrese al siguiente enlace: Video_Dosificador (https://drive.google.com/file/d/1d03DrYTD_aRa6-jkqa5merPkhtxKRVwd/view).

FACTOR K

Cuando el líquido fluye a través de la tubería, hace girar el rodete, en el interior del cual hay 4 imanes que generan una señal de medición en el transductor.

La tensión inducida, dependiente de la frecuencia de giro, es proporcional a la velocidad de caudal de fluido. Para convertir la frecuencia en velocidad de caudal se necesita un coeficiente de correlación, que depende del tamaño y material de la tubería. El coeficiente de correlación (factor K en pulsos/litro) puede localizarse en el manual de instrucciones del fitting (S030).


CONEXIÓN Y UBICACIÓN DEL DOSIFICADOR

Actualmente el dosificador solo cuenta con las conexiones a relés 1 y 2, la tensión de alimentación a 230VAC y los hilos rojo negro y amarillo (que ya vienen conectados de fabrica), no tiene cables en las entradas binarias IN1..IN4 ni la salida OUT.

Otro detalle del conexionado es que las conexiones a relés si tienen cable, pero no están conectadas al PLC.

Dosificador del sistema

NOTAS

- Para obtener el valor del factor k debe optar por 2 procedimientos una por tablas “TEACH-NO” u otro calculando con un volumen conocido de líquido que pasa a través de la tubería” TEACH-SI”, en este caso se tiene un Factor-k = 115.8 por tablas para tuberías DN15, pero calculado se tiene un Factor-k = 66.63.
- Haciendo pruebas se tiene que el Factor-k hallado experimentalmente es el correcto, el correspondiente a las tuberías de DN15 por tablas esta erróneo por el tipo de instalación que se tiene del dosificador (se puede ver los tipos de instalación correcta en el manual del fitting S030).
- Para el modo de funcionamiento automático se debería hacer la conexión de la electroválvula KV3 al PLC, esto no se hizo porque de todas formas al probar los relés de forma manual en el modo de pruebas se comprobó que la electroválvula no está en funcionamiento, esto debido a los mismos problemas que se tuvo en las otras 2 electroválvulas, además de que como se mencionó las entradas digitales no tienen cableado. Por lo tanto, no se puede usar el modo de funcionamiento automático y tampoco se puede usar al dosificador como control de flujo simplemente se lo usa como instrumento de medición, tanto para volumen como para caudal de líquido.
- Para el manejo del dosificador se tiene los procedimientos muy bien explicados en el manual en español del dosificador Burkert 8035 o también en el video realizados.
  4.5. SENSOR DE ULTRASONIDO

Un sensor ultrasónico es un dispositivo electrónico que mide la distancia de un objeto objetivo mediante la emisión de ondas de sonido ultrasónicas y convierte el sonido reflejado en una señal eléctrica.

873P-DCAC1S-D5-ALLEN-BRADLEY

El sensor de ultrasonido Allen modelo 873P-DCAC1S-D5 es un sensor ultrasónico programable ideal para medir la altura del nivel de líquido, tiene un rango de medición de 150 a 1500 mm.

El sensor cuenta con 5 pines los cuales 2 son para alimentación de 19 a 30 VDC, 2 de la salida discreta P1 y P2, y 1 de la salida analógica de corriente entre 4 a 20 mA.

Información básica en la etiqueta del sensor ultrasónico

Debido a que este sensor nos proporciona corriente cuyo valor es proporcional a la distancia medida, esta señal debe adaptarse de manera que pueda ser entendida por el usuario. En nuestro caso, utilizaremos un escalamiento por software para ver lecturas en centímetros.

pines

La programación se lo realiza con el botón de configuración que se encuentra en la parte posterior del sensor, eligiendo los puntos P1 y P2, también cuenta con 3 led’s indicadores 2 amarillos que corresponden a P1 y P2, y 1 led verde para indicar si un objeto está presente en el rango del sensor.

Vista superior

Sensor ultrasónico

Led

indicador

Botón de

Configuracion

Para la programación del sensor puede ver el siguiente video SensorUltrasonico-AllenBradley 873P-DCAC1S-D5 (https://drive.google.com/file/d/1WP8aqPLlU2HpXscduLGyWxW0oLEFOP9I/view?usp=share_link)

Para una explicación acerca del funcionamiento del sensor puede ver el siguiente video: PrincipioDeFuncionamiento-SensorUltrasonico (https://drive.google.com/file/d/17lU3JMBDOoRHcww7jkHOZkzxXglrWXHR/view?usp=share_link)

CONEXIÓN DEL SENSOR ULTRASONICO CON EL MODULO DE EXPANSION MICROLOGIX 1762

El sensor cuenta con 5 pines, donde 2 son para el voltaje de alimentación, 1 es la salida de corriente (cable negro), el cual se encuentra conectado al módulo de expansión del PLC MicroLogix 1100, ya que es una señal de corriente analógica, esta salida está conectada a la entrada I:0.1 del módulo con cable de color azul y como etiqueta color verde A-1000.

Dos pines del sensor que corresponden a los puntos P1 (blanco) y P2 (gris), que corresponden a las salidas discretas, no están conectadas.

NOTAS:

Respecto a las pruebas del sensor

- El sensor es indiferente si se toman lecturas con materiales solidos o líquidos, siempre y cuando el sensor sea programado en el rango de funcionamiento.
- Si no se toma en cuenta la zona ciega del sensor, que consiste en los primero 15 cm, las lecturas podrían ser no fiable.
- El rango de funcionamiento del sensor, se cumple cuando el eco se produce sobre una superficie plana paralela a la membrana del sensor.
- El rango de funcionamiento del sensor, se reduce cuando el eco se produce sobre una superficie con una inclinación o deformación considerable.
- La calibración del sensor ya está realizada por el fabricante, no es recomendable intervenir el funcionamiento interno sin contar con la instrumentación adecuada.
- El rango de corriente entregada por el sensor de acuerdo a las mediciones es como mínimo 3.8 mA y como máximo 19.8 mA.

Respecto a la programación del sensor

- Se tiene aproximadamente un minuto para establecer P1 o P2 una vez que esté en el modo de programación. Después de un minuto, el sensor saldrá del modo de programación.
- Cambiar las distancias del punto de ajuste después de que se hayan programado requiere reprogramar el sensor. La reprogramación de cada punto de ajuste se puede hacer independientemente del otro.
- Los puntos de ajuste se pueden programar en cualquier orden

Para más información revisar el Datashet SU (https://drive.google.com/file/d/16lIDooVH8DEMBvNuiLWUEy-iPI3WfyDV/view?usp=share_link) que nos brinda el fabricante.

  4.6. SENSORES VIBRATORIOS

Basados en la detección de la variación en la frecuencia de resonancia de un metal sumergido en distintos fluidos. Los interruptores de nivel, al igual que los sensores de nivel, son instrumentos de medición utilizados principalmente para detectar el nivel de llenado de productos almacenados en tanques, silos y otros depósitos de almacenamiento.

SENSOR VIBRATORIO (Endress+Hauser Liquiphant T FTL20-0024 DC-PNP)

Mientras que los sensores de nivel efectúan una medición continua del nivel del producto, los interruptores de nivel realizan una medición puntual, es decir, detectan la presencia o ausencia del producto en un nivel predefinido.

Cuando el producto entra en contacto con la sonda vibrante, amortigua las vibraciones. Al detectar la alteración de amplitud y de frecuencia de las vibraciones, el interruptor cambia de estado y esto es visible gracias a los indicadores lumínicos que tiene incorporado (luz verde y roja).

Cubierta transparente del sensor para la visualización del estado

Horquilla vibrante

Sensor vibratorio

En la modelo del sensor usado se cuenta con 4 clavijas, 2 corresponden a la alimentación, una salida digital de 0V a 24VCC y una tierra. Para alimentar el sensor y transmitir la señal digital hacia el PLC se utiliza el conector Solenoidal (GDM Black).

CONEXIÓN AL PLC MICROLOGIX 1100 Y SU UBICACIÓN

A través del PLC MicroLogix 1100 se obtiene la lectura de la señal emitida por el sensor, para usarse de la manera en la que se vea conveniente. Este sensor se ubica en la parte lateral del sistema, pero lee los cambios de nivel de la parte interna del tanque superior.


Ubicación de los sensores de nivel

Conexión al PLC

  4.7. SENSOR DE PRESIÓN

Los transductores de presión capacitivos son medidores que se basan en la utilización de un elemento elástico cuya deformación, proporcional a la diferencia de presión entre ambos lados de ese elemento elástico, se convierte en una señal eléctrica.

CERABAR T-PMC131


Conector solenoidal

Membrana capacitiva y circuito electrónico

El sensor de presión cerabar T-PMC131 es un sensor capacitivo ideal para medir presión absoluta o relativa, tiene un rango de medición de 0 a 200 mbar con una presión máxima de trabajo de 3.3 bar y cuenta con protección IP65 (para más detalle revisar la hoja de datos del sensor (https://drive.google.com/file/d/1MRcmQot7yp1qFLxcF4IfYo5lmqkd2dnu/view?usp=sharing)).

Es un sensor capacitivo con membrana interna, porque el sensor está abierto y en contacto con el exterior; esto indica que el sensor es susceptible a obstrucción y los líquidos viscosos no se eliminan por completo por lo que la existencia de residuos es una posibilidad

Sensor de presión PCM131

El sensor cuenta únicamente con 2 hilos conectores los cuales alimentan al sensor con 24 VCC y de respuesta este proporciona una corriente entre 4 a 20 mA por el mismo cable conductor (figura 1).

Debido a que este sensor nos proporciona corriente cuyo valor equivale a la presión medida, esta señal debe adaptarse de manera que pueda ser entendida por el usuario. En nuestro caso utilizaremos un escalamiento por software, para ver lecturas en milibares, en la sección de adaptación de señales.

Etiqueta del código del producto

UBICACIÓN DEL SENSOR EN EL SISTEMA


Este sensor se ubica en la parte trasera del sistema, pero lee las variaciones de presión de la parte interna del tanque superior

Vista del interior del tanque superior

Vista de la parte trasera del sistema

ECUACIONES QUE DESCRIBEN SU MEDICIÓN

La presión que nuestro sensor puede manejar es de 0 - 200mb por ello tenemos que realizar un escalamiento para relacionar la corriente con la presión; es por ello que las medidas tomadas serán altura del líquido y corriente de salida del sensor; la altura nos proporciona de manera indirecta la presión relativa con respecto al punto en el que está ubicado el sensor de presión.

P=ghρ Donde: g≈9.775m/(s^2) ρ_(agua) =1000(Kg)/(m^3)

Además, como el sensor se encuentra a 5 cm por encima de la parte inferior del tanque se debe de restar una distancia de 5cm a partir de que el agua este en contacto con el sensor.

P[Pa]=ρ_(agua) *(h-5)/100*g → 1[Pa]=0.01 [mbar] → P=ρ_(agua) *(h-5)/100*g*0.01 [mbar]

CONEXIÓN DEL SENSOR

Para realizar la adaptación de señales se deberá de conectar un terminal de la alimentación del sensor en el módulo de expansión del PLC, como se muestra en la figura:


Conexión del sensor de presión al PLC micrologix 1100

NOTAS

- Las pruebas realizadas con el sensor dieron a conocer que este presenta un error de punto cero (pues comienza la medición en 3.9mA y no en 4mA), esto se puede solucionar realizando la calibración respectiva o mediante la adaptación de señales por software.
- Debido a que La Paz tiene 495 mmHg (660 mbar) la presión medida nunca sobrepasara el máximo valor de presión que puede soportar.
- La mala disposición en la que se encuentra el sensor en el tanque produce una medición de presión inferior a la medida real.
  4.8. SENSORES DE TEMPERATURA

El sistema cuenta con 2 tipos de sensores las cuales son la Termocupla TD12 y el sensor de temperatura RTD OMNIGRAND T TST487. Estos sensores se ubican en la parte trasera del sistema y se conectan al controlador de temperatura

SENSOR RTD

SENSOR TC

4.8.1. Termocupla (TC)

Una termocupla se hace con dos alambres de distinto material unidos en un extremo. Al aplicar temperatura en la unión de los metales se genera un voltaje muy pequeño (efecto Seebeck) del orden de los milivolts el cual aumenta con la temperatura.

Por ejemplo, una termocupla “tipo J” está hecha con un alambre de hierro y otro de constantán (aleación de cobre y niquel) Al colocar la unión de estos metales a 750 °C, debe aparecer en los extremos 42.2 milivolts.

Termocupla TC 12

Los sensores de temperatura de la gama TC 12 Omnigrad M son termopares diseñados para su uso en la industria química fina, pero también adecuados para aplicaciones generales. Están compuestos por una sonda de medida con pozo de protección, y una carcasa, que puede contener el transmisor para conversión de la variable medida (4…20 mA).

Este sensor de tipo J Hierro y Constantán, tiene un rango de trabajo de -40 C° a 750 °C es apto para zonas con peligro de explosión, su máxima presión de proceso a 20 °C es de 40 bar. Para más información revisar el Datashet_TC (https://bdih-prod-assetcentralapi-assetcentral-rest-srv.cfapps.eu10.hana.ondemand.com/files/DLA/4B5996F491EB46E8E10000000A35E042/TI275ten_0204.pdf) que brinda el fabricante.

Termocupla TC 12

4.8.2. Resistencia Variable (RTD)

Los RTD son sensores de temperatura resistivos. En ellos se aprovecha el efecto que tiene la temperatura en la conducción de los electrones para que, ante un aumento de temperatura, haya un aumento de la resistencia eléctrica que presentan

Puede conectarse a 2, 3 y 4 hilos dependiendo su uso.

- hilos: Se utiliza la conexión de 2 hilos para aminorar costos cuando no se requiere mayor precisión.
- hilos: Es la opción intermedia entre 2 y 4 hilos. Su elección dependerá del uso, el tipo de sensor y los requerimientos de medida.
- hilos: Se utiliza cuando las mediciones se vuelven más exigentes y es necesario disminuir el aporte resistivo de los cables.

OMNIGRAD T TST487

Este sensor RTD es un tipo Pt100 las cuales deben su nombre al hecho de estar fabricados de platino (Pt) y presentar una resistencia de 100ohms respectivamente a 0° C.

Tiene la conexión de cuatro hilos, lo cual hace al sensor más preciso. Tiene un rango de temperatura de -50°C a + 300°C, máxima presión de proceso (estática): 20 °C: 20 bar. Son relativamente inmunes al ruido eléctrico. Para más información revisar el Datashet_RTD1 (https://bdih-prod-assetcentralapi-assetcentral-rest-srv.cfapps.eu10.hana.ondemand.com/files/DLA/0200030000091ED785BBCB2AC220053F/CP01266Z.pdf)que brinda el fabricante.

Una importante característica del sensor es que se debe hacer pasar una cierta corriente I por el elemento sensor de modo de poder medir su resistencia. Esta corriente I llamada “corriente de excitación” la suministra el instrumento lector y es del orden de 0.1 mA a 2 mA.

OMNIGRAD T TST487

*La conexión de estos sensores se la explicara conjuntamente con el controlador de temperatura.

Notas:

- Los sensores de temperatura no se encontraban conectados al controlador de temperatura, por lo que se procedió a conectarlos para su correcto funcionamiento.
- Los sensores RTD son de mayor precisión esto se debe al método de 4 hilos, 4 cables que son distintos (distinta resistencia), no solo proporciona una buena precisión, sino que también proporciona una excelente estabilidad y repetibilidad.
- Se debe hacer pasar una cierta corriente I por el elemento sensor de modo de poder medir su resistencia, la cual la suministra el instrumento lector es decir el controlador de temperatura.
- El sensor TC tiene mayor alcance a comparación del sensor RTD
5. CARACTERIZACION DE SENSORES Y ACTUADORES

En este apartado se pretende presentar la caracterización mediante pruebas realizadas en laboratorio a cada sensor y actuador que conforma la planta nivel de líquido, donde se optó por la medición de la magnitud o variable que el sensor maneja y su interacción con la planta, obteniendo graficas con variables tales como: corriente, tensión, altura, frecuencia, temperatura y resistencia que nos ayuda a saber cómo funciona el sensor o actuador.

MOTOR BOMBA

El variador de frecuencia será encargado de poder regular la tensión suministrada al motor bomba, debido a esto se puede crear una gráfica comparativa entre ambas variables, observando y tomando registro del estado de tensión de salida del motor al variar la frecuencia de entrada al mismo.

TABLA Y GRAFICO FRECUENCIA VS VOLTAJE (AC)

Frecuencia [Hz] | Voltaje [VAC]
0,3 | 3
3 | 28,6
6 | 42,1
9 | 53,3
20 | 98,4
25 | 120,9
30 | 147,1
35 | 173
40 | 199,6

Los valores de frecuencia y de voltaje fueron obtenidos directamente del variador de frecuencia, ya que este cuenta con la opción de visualización de frecuencia y su correspondiente valor en voltaje alterno a dicha frecuencia elegida o regulada, el cual va hacia el motor bomba.

En la gráfica se observa un comportamiento muy próximo a ser lineal al compararlo con línea de tendencia lineal, lo cual nos indica que las variaciones de frecuencia corresponden de forma muy próxima a las de tensión, observando también el correcto escalamiento que presentan ambas variables, donde un valor mínimo de frecuencia de 0 Hz involucra una tensión de 0 VAC y un valor máximo de frecuencia de 50 Hz significa un valor de 230 VAC.

Cabe señalar la ausencia del dato máximo debido a que estos valores (50Hz – 230VAC) ocasionan un consumo de corriente cercano a los 5 [A], lo que provoca que los switch térmicos salten y desenergicen el sistema, esto debido a que fueron dimensionados para tolerar solo 5[A].

DOSIFICADOR

TABLA Y GRAFICA COMPARATIVA ENTRE VOLTAJE VS CAUDAL

Caudal (L/s) | Voltaje (V)
0.118 | 99.7
0.184 | 110
0.22 | 120.7
0.29 | 140.2
0.322 | 149.8
0.352 | 160.3
0.383 | 170.2
0.42 | 180.2

En la prueba de laboratorio, con ayuda del variador de frecuencia, se obtuvo una relación lineal entre el voltaje y el caudal esto para tener información del caudal que es capaz de suministrar la bomba en base al voltaje de funcionamiento del mismo.

Los valores de voltaje fueron obtenidos directamente del variador de frecuencia, ya que este cuenta con la visualización de voltaje al variar y regular la frecuencia. Los valores de caudal fueron obtenidos del dosificador, observando la variación del mismo ante la variación de voltaje que le llega al motor bomba.

SENSOR DE ULTRASONIDO

TABLA Y GRAFICA COMPARATIVA ENTRE ALTURA VS CORRIENTE

Con la ayuda de un multímetro se realizó la medición de corriente analógica proporcionada por el sensor en función a la altura del nivel de líquido del depósito, obteniendo la siguiente grafica comparativa entre Altura vs Corriente:

Corriente [mA] | Altura [cm]
3,8 | 0
5,4 | 5
7,3 | 10
9,2 | 15
11,1 | 20
13,3 | 25
15,4 | 30
17,3 | 35
17,9 | 36,5

Con esta grafica que corresponde a las mediciones realizadas podemos aseverar que este sensor es un sistema lineal, dinámico, estacionario y causal.

Los datos de altura fueron tomados visualmente de una cinta métrica colocada al costado del tanque superior y los datos de corriente (correspondiente a una altura) fueron medidos con un multímetro.

Esta prueba es realizada con el fin de obtener el equivalente de la señal analógica (corriente) con respecto a una altura cualquiera, que por motivos de la gráfica fueron dándose de 5 en 5 de forma ascendente.

Estos datos son de mucha ayuda para la adaptación de señales que se realiza al presente sensor.

SENSOR DE PRESION

TABLA Y GRAFICA COMPARATIVA ENTRE ALTURA VS CORRIENTE

Corriente mA | Altura cm | Presión mbar
3.9 | 0 | 0.00
4 | 5 | 0.00
4.43 | 10 | 4.89
4.81 | 15 | 9.78
5.19 | 20 | 14.66
5.57 | 25 | 19.55
5.97 | 30 | 24.44
6.38 | 35 | 29.33
6.49 | 36.5 | 30.79

Los datos de altura fueron tomados visualmente de una cinta métrica colocada al costado del tanque superior y los datos de corriente (correspondiente a una altura) fueron medidos con un multímetro.

Esta prueba es realizada con el fin de obtener el equivalente de la señal analógica (corriente) con respecto a una altura cualquiera, que por motivos de la gráfica fueron dándose de 5 en 5 de forma ascendente.

Estos datos son de mucha ayuda para la adaptación de señales que se realiza al presente sensor.

Con esta grafica podemos aseverar que este sensor es un sistema lineal, estacionario y causal; además, podemos indicar que su rango de trabajo de 0 – 200 mbar (presión relativa) esta calibrado para su funcionamiento en ciudad de La Paz de manera que puede soportar hasta 3.3 bar como presión absoluta (660 mbar + 200mbar = 860 mbar).

SENSOR DE TEMPERATURA TC

TABLA Y GRAFICA COMPARATIVA ENTRE VOLT. VS TEMP.


Con la gráfica se puede observar que el sensor es un sistema dinámico, estacionario, lineal y causal

SENSOR DE TEMPERATURA TC
T [°C] | V [mV]
26 | 0
30 | 0,1
32 | 0,2
33 | 0,4
35 | 0,5
36 | 0,6
39 | 0,7
42 | 0,8
46 | 1
50 | 1,3
55 | 1,5
58 | 1,7
60 | 1,8
65 | 2,1
67 | 2,2

SENSOR DE TEMPERATURA RTD

TABLA Y GRAFICA COMPARATIVA ENTRE RESIST. VS TEMP.

TEMPERATURA RTD
T [°C] | V m[V] | I mA | R [Ω]
19 | 107 | 1 | 107
25 | 110,4 | 1 | 110,4
30 | 118,3 | 1 | 118,3
39 | 121,6 | 1 | 121,6
50 | 122,5 | 1 | 122,5
61 | 125,4 | 1 | 125,4
65 | 129,5 | 1 | 129,5
80 | 135 | 1 | 135
85 | 137 | 1 | 137
99 | 141,2 | 1 | 141,2
120 | 151 | 1 | 151
135 | 156,1 | 1 | 156,1

Con esta grafica podemos observar la comparación con Pt100 teórico y Pt100 en laboratorio, este sensor es un sistema dinámico, estacionario, lineal y causal.

6. CONTROLADORES

El proceso cuenta únicamente con un lazo de control que con ayuda de un PLC nos permite medir el nivel con los distintos sensores y accionar al motor a través del variador; sin embargo, adicionalmente se cuenta con un controlador de temperatura el cual se ocupa como un indicador.

    6.1. CONTROLADOR LÓGICO PROGRAMABLE MICROLOGIX 1100

El controlador de la serie MicroLogix 1100 cuenta con 10 entradas de 24 VDC y 6 salidas de relé, un puerto Ethernet/IP para comunicaciones con HMI y soporta hasta 4 expansiones de la variedad de módulos 1762.

Los controladores Micrologix son apropiados para una amplia variedad de aplicaciones de control simples, hechas más fáciles gracias a su pantalla LCD que facilita el monitoreo e interacción con los programas de control. La programación se realiza con la aplicación Rslogix 500, con posibilidades de edición en línea que permite hacer modificaciones con los programas en funcionamiento.

Este controlador se puede disponer para caracterizar de manera individual cada uno de los transductores de manera aislada, para ello se utilizarán las salidas de relé para el accionamiento de las electroválvulas, también realizará la adaptación de señales para los sensores de presión y de ultrasonido, y finalmente nos permitirá accionar el variador de frecuencia de manera automática.

El módulo de expansión que utiliza el controlador es el 1762-IF20F2, el cual es un módulo analógico de voltaje/corriente con combinación de 2 canales de entrada y 2 canales de salida. Los 2 canales de entrada se utilizarán para las lecturas del sensor ultrasónico y el sensor de presión.

El diseño del sistema MicroLogix 1100 solo permite expandir hasta cuatro módulos de E/S 1762.

Las entradas analógicas del PLC convierten las señales de corriente y voltaje en valores binarios de complemento dos de 16 bits. Dependiendo del tipo de sensor que se utilizará se tendrá una señal analógica especifica y dependiendo al tipo de configuración de la señal analógica se tendrá 2 maneras de generarla (para control PID, o proporcional).

Rango de Voltaje / Corriente | Para PID | Proporcional
0 a 10V DC | 0 a 16,384 | 0 a 32,7768
4 a +20 mA | 3,277 a 16,384 | 6,552 a 32,760

Para más información revisar el manual del PLC (https://drive.google.com/file/d/1GX2UjoSn0mVqp8_IO84a8d0JNCxCAqNC/view?usp=sharing) y del módulo de expansión (https://drive.google.com/file/d/1z4HPtHHQMMmsGZHh6Rkc7iYpUPIUVD8d/view?usp=share_link)

    6.2. CONTROLADOR DE TEMPERATURA ALLEN BRADLEY 900-TC16

Este controlador tiene la característica de aceptar distintos modelos de sensores de temperatura todas las termocuplas del mercado y RTD's. Tiene una frecuencia operativa de 50-60 Hz y una alimentación de 220 VAC (Para evitar dañar al usuario tiene un protector para dedos que evita electrocutarnos).

El controlador de temperatura 900-TC16 cuenta con las siguientes entradas y salidas


- Entrada de milivoltios: 0 a 50 mV
- Entrada de voltaje analógico: 1 a 5 Vcc, 0 a 5 Vcc y 0 a 10 Vcc
- Entrada de corriente analógico: 4 a 20 mA y 0 a 20 mA
- Entrada de evento: salida de corriente: aprox. 7 mA por contacto.
- Entrada de contacto: ON: 1k max., OFF: 100 k min
- Entrada sin contacto: ON, OFF
- Salida de control 1
- Salida de control 2
- Salida de alarma

Parte frontal del controlador de temperatura

NOMBRE DE LOS COMPONENTES PANEL FRONTAL

Tecla de grupo de funciones

Tecla de modo

Pantalla N°1

Pantalla N°2

Tecla arriba y abajo

DIAGRAMA DE CONEXION

CONEXIONES REALIZADAS EN EL SISTEMA

Alimentación

220 VAC

Salida 4-20 mA

Entradas de los sensores PT y TC

Entradas y salidas del controlador de temperatura

Los dos cables superiores son su salida 4-20 mA. Los tres inferiores a la izquierda son para la entrada del sensor y los dos blancos son la alimentación 220V AC del equipo. Este cableado es realizado con la información que brinda el fabricante en su Datashet (https://literature.rockwellautomation.com/idc/groups/literature/documents/in/900-in020_-mu-e.pdf).


Conexión para visualizar el sensor RTD

Conexión para visualizar el sensor TC

La figura muestra la parte frontal del panel de control, específicamente la conexión y visualización del controlador de temperatura, teniendo a la izquierda la conexión para el sensor RTD y a la derecha la conexión para el sensor TC.

Después de conectarlos correctamente configuramos el controlador, los pasos a seguir son los siguientes:

1. Energizar el sistema
2. Se debe presionar el primer botón Figura1-1, que es de selección de grupo, por cuatro de segundos y en la primera opción iN-t Figura1-2 seleccionar el número (con la tecla arriba o abajo)
- Numero 1 para el sensor de temperatura RTD
- Numero 7 para la termocupla J

Esta información está en el manual con el que viene el equipo.

3. Luego retornamos presionando el mismo botón por cuatro segundos y ya deberíamos tener la temperatura en la pantalla Figura1-3.


Figura 1-1

Figura 1-2

Figura 1-3

NOTA:

- El sistema de nivel de líquido cuenta en la parte frontal del tablero con conectores hembra del tipo banana para realizar la conexión al controlador, pero no se contaba con conectores del tipo banana-banana; es por esta razón que se adquirieron 3 conectores banana-banana para poder utilizar el controlador de temperatura, por el momento, como un indicador.
7. ADAPTACION DE SEÑALES

La adaptación de señales es la manipulación de una señal analógica de tal manera que cumpla con los requisitos de la siguiente etapa para su procesamiento posterior.

En aplicaciones de ingeniería de control , es común tener una etapa de detección (que consiste en el uso de un sensor), una etapa de acondicionamiento de señal (donde generalmente se realiza la amplificación de la señal) y una etapa de procesamiento (a menudo llevada a cabo por un ADC y un microcontrolador).

El acondicionamiento de señales se puede realizar por hardware (utilizando un circuito electrónico) o por software (utilizando un PLC o microcontrolador).

ADAPTACION DE SEÑALES POR SOFTWARE EN EL PLC


Para realizar la adaptación de señales usaremos la función SCP en la programación en Ladder en el software rslogix micro english pues nos permite realizar un escalamiento sencillo delimitando únicamente los valores mínimos y máximos de la representación binaria que tiene el PLC con relación a la señal analógica de salida que nos proporciona nuestro sensor.

En la práctica se deberá de utilizar la configuración para 4mA – 20mA (Min: 3277 - Max:16384) pues se utilizará para acondicionar la señal de salida del sensor de presión y de ultrasonido; también, se deberá de elegir si trabajar únicamente con valores enteros o utilizar salidas flotantes para la visualización con decimales.

Configuración en Rslogix Micro English

Para el sensor de ultrasonido se definirá una escala con un mínimo de 0cm y un máximo de 50cm; además, se utilizarán salidas con números enteros para trabajar con una medida redondeada muy próxima a la medida real. Y para el sensor de presión se definirá una escala mínima de 3mbar y un máximo de 200mbar, esto debido a que el sensor se encuentra mal calibrado y entrega medidas negativas, y se decidió trabajar con salidas flotantes.

Adaptación de señales para el sensor de presión

Adaptación de señales para el sensor de ultrasonido

8. OBSERVACIONES, RECOMENDACIONES y CONCLUSIONES

El sistema de nivel de líquido cumple con su funcionamiento, sin embargo, se debe considerar las observaciones siguientes:

- La ubicación del sensor de presión debería estar más por debajo de la ubicación actual, debido a que actualmente la referencia para medir la presión no está ubicada en el fondo del tanque.
- El estado de las electroválvulas inicialmente era defectuoso, sin embargo, con una limpieza interna se consiguió corregir el estado de ellas (KV1) y (KV2), esto siguiendo su manual y hoja de datos.
- Uno de los breackers (termicos) podría estar mal dimensionado, debido a que este “salta” o corta el suministro de energía hacia el variador de frecuencia y por ende al motor, cuando se exige su máxima capacidad de 5 [A].
- El sensor vibratorio superior está ubicado por encima del desemboque de agua para el llenado del tanque, provocando que el motor realice un mayor esfuerzo.
- La ubicación del sensor ultrasónico se encuentra 5 cm por encima del depósito, la altura del depósito es de 50 cm, haciendo un total de 55 cm, tomando en cuenta la zona ciega del sensor que es de 15 cm, la altura aprovechable del depósito es de 40 cm, para que las lecturas sean fiables.

Para un mejor desarrollo del laboratorio podemos recomendar lo siguiente:

- Con la implementación de un lazo de control adicional, para la variable de temperatura, añadiendo un calentador como actuador acoplado a la salida del controlador de temperatura.
- Con el funcionamiento eficiente de ambas electroválvulas el sistema podría regular de forma adecuada el suministro de agua hacia el tanque superior para un correcto control de nivel del líquido.

Finalmente, podemos concluir que:

- Durante el proceso se desarrollaron habilidades y destrezas sobre la instrumentación con el fin de poder reconocer, adaptar y caracterizar sensores y/o actuadores, los cuales abundan en el área profesional y son de vital importancia poder conocerlos y manipularlos.
- Para el proceso se utilizó el estándar de la norma ISA para describir el diagrama de tuberías P&ID, obteniendo así el conocimiento sobre dicho estándar y reglas que este cumple.
- También se logró identificar que el sistema tiene la función de realizar el control de nivel de líquido utilizando los sensores de nivel y el motor como actuador. Adicionalmente el sistema es aprovechado para realizar la medición de presión, temperatura y caudal para brindar información al usuario.

Además, se consiguió caracterizar los elementos que componen al sistema (sensores y actuadores) de forma tal de tener información adecuada y necesaria para el funcionamiento del sistema e implementar un futuro control de nivel.

- Finalmente, se realizó la adaptación de señales por software (con ayuda del PLC) para las medidas tomadas por los sensores de presión y de nivel de ultrasonido
9. BIBLIOGRAFIA (DATASHEET O MANUALES)

Asignar IP y configurar Software para el uso del controlador MicroLogix 1100

https://www.youtube.com/watch?v=oTb93HQi4Is

Manual en español del PLC micrologix 1100 1763-L16BWA

https://drive.google.com/file/d/1GX2UjoSn0mVqp8_IO84a8d0JNCxCAqNC/view?usp=sharing

Módulo de expansión 1762-IF2OF2

https://drive.google.com/file/d/1z4HPtHHQMMmsGZHh6Rkc7iYpUPIUVD8d/view?usp=share_link

Manual en ingles del Sensor de proximidad ultrasónico programable 873P

https://www.ideadigitalcontent.com/files/11994/873p-in005_-en-p.pdf

Manual del Sensor de temperatura RTD Omnigrad T TST487

https://bdih-prod-assetcentralapi-assetcentral-rest-srv.cfapps.eu10.hana.ondemand.com/files/DLA/4A09797F65AC13B6E10000000A35E042/TI147ren_0309.pdf

Manual del Sensor de temperatura TC12

https://bdih-prod-assetcentralapi-assetcentral-rest-srv.cfapps.eu10.hana.ondemand.com/files/DLA/4B5996F491EB46E8E10000000A35E042/TI275ten_0204.pdf

Manual del controlador de temperatura BULLETIN 900-TC

https://literature.rockwellautomation.com/idc/groups/literature/documents/sg/900-sg001_-en-p.pdf

Hoja de datos motor trifásico CMT 100/00

https://www.afripumps.co.za/images/stories/virtuemart/pdfs/Pentax_CM_series.pdf

características para elegir un motor eléctrico

https://brr.mx/claves-para-elegir-un-motor-electrico-para-pequenos-accionamientos/

Hoja de datos de electroválvulas

https://drive.google.com/drive/folders/1B0dygrrIcW1Ykk_nfe6dE17ElPQJsYh5?usp=sharing

Variador de frecuencia ajustable de CA

https://drive.google.com/file/d/1-xUMAyj1BGngUbKiT9Q-8fwbbRxXZPqO/view?usp=sharing

Información técnica cerabar T PMC131/PMP131/PMP135

https://drive.google.com/file/d/1MRcmQot7yp1qFLxcF4IfYo5lmqkd2dnu/view?usp=sharing

Manual en español Dosificador Burkert 8035

https://www.burkert.com/en/Media/plm/MAN/MA/MA8035-BatchFlow-ES-ES.pdf?id=MAN0000000000000001000111876ES-

Manual en ingles Dosificador Burkert

https://www.burkert.com/en/Media/plm/MAN/MA/MA8025-MAN-BATCH-EU-EN.pdf?id=MAN0000000000000001000199281ENF

Manual de instrucciones fitting S030 | Racor de sensor Inline

https://www.burkert.com/en/Media/plm/MAN/MA/MAS030-Standard-ES-ES.pdf?id=MAN0000000000000001000095105ESB

Datasheet Endress+Hauser Liquiphant FTL20-0024

https://bdih-prod-assetcentralapi-assetcentral-rest-srv.cfapps.eu10.hana.ondemand.com/files/DLA/479DBB49B5B94677E10000000A35E035/TI364Fen_0108.pdf

Principio de Medición Vibratorio (Endress+Hauser)

https://youtu.be/FL5Tg4sRrmk

A. Benitez (2017), elaboración e implementación de prácticas de laboratorio, para el uso en kit didáctico de instrumentación de control industrial, con PLC. Universidad Mayor De San Andres [Proyecto De Grado].

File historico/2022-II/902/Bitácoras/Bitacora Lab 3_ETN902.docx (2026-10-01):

Universidad “Mayor de San Andrés”

FACULTAD DE INGENIERIA

CARACTERIZACION DEL SISTEMA DE NIVEL DE LIQUIDO.

Integrantes: Univ. Espino Marca Mary Isabel

Univ. Condori Mamani Roger

Univ. Linares Poma Guido Alvaro

Carrera: Ing. Electrónica

Materia: ETN 902 / ETN 1034

Docente: Ing. Jorge A. Nava A.

Auxiliares: Univ. Huarachi M. Rhem J.

Univ. Huanca Mita Miguel

Fecha: 8/11/2022

La Paz – Bolivia

TABLA DE CONTENIDO

1. OBJETIVOS 3

2. DESCRIPCION DEL PROCESO 3

3. PROCESO DE NIVEL DE LIQUIDO 3

3.1. Estructura del sistema: 3

3.2. Componentes del sistema: 3

3.3. Funcionamiento 3

3.4. Puesta en marcha del Sistema 4

3.5. Esquema P&ID 6

3.6. Función de transferencia 7

3.7. Esquema eléctrico 8

4. INSTRUMENTACIÓN 10

3.1 Controladores 10

3.1.1 Controlador Lógico Programable micrologix 1100 10

3.1.2 Controlador de Temperatura Allen Bradley 900-TC16 11

3.2 BOMBA DE AGUA 14

3.3 Variador de frecuencia 17

3.4 Electroválvulas 18

3.5 Dosificador 20

3.6 Sensor de ultrasonido 23

3.7 Sensores vibratorios 27

3.8 Sensor de presión 30

3.9 Sensores de Temperatura 32

3.9.1 Sensor de temperatura TC 32

3.9.2 Sensor De Temperatura RTD 34

5. ADAPTACION DE SEÑALES 36

6. OBSERVACIONES, RECOMENDACIONES y CONCLUSIONES 37

7. BIBLIOGRAFIA (DATASHEET O MANUALES) 38

1. OBJETIVOS
- Desarrollar habilidades y destrezas en la instrumentación de laboratorio y proceso.
- Representar al proceso en su totalidad utilizando la normativa ISA (P&ID)
- Identificar y Caracterizar los elementos que componen al sistema (sensores y actuadores)
- Identificar y Realizar la adaptación de señales para aquellos transductores en los que sea necesario
2. DESCRIPCION DEL PROCESO

Este sistema tiene la función de medir el nivel de líquido en un área contenida. Se utiliza para evitar que los niveles de líquido se pongan excesivamente altos o bajos y para mantener un volumen deseado de líquido contenido en el tanque.

En este caso también puede obtenerse información de temperatura y de presión.

3. PROCESO DE NIVEL DE LIQUIDO
  3.1. Estructura del sistema:


- Estructura metálica color azul
- Dos tanques de almacenamiento de agua
- Soporte para sensores y tablero de control
- Tuberías de ½ y ¾
  3.2. Componentes del sistema:
- 2 sensores vibratorios
- 2 electroválvulas
- Flujómetro digital (Dosificador)
- Sensor de presión
- Sensor de temperatura TC (Termocupla)
- Sensor de temperatura RTD (Resistivo)
- Controlador de temperatura
- motor trifásico de 1HP
- Variador de frecuencia
- Sensor de Ultrasonido
- PLC (Micrologix 1100)
- 1 módulo de expansión (para PLC)

Vista frontal del sistema

- Fuente de alimentación de 24V
- Pantalla de 6 pulgadas touch Panelview C600
  3.3. Funcionamiento
- Sensores vibratorios: Es utilizado para la detección de nivel alto y bajo del líquido en el tanque.
- Sensor ultrasónico: Es utilizado para la medición de la altura del nivel de líquido del depósito.
- Sensor de presión: Es utilizado para la medición de presión relativa en el tanque y también se puede usar para medir la altura del líquido teniendo como referencia la posición de este sensor.
- Sensores de temperatura TC/RTD: Están conectados al controlador de temperatura para dar mediciones de la temperatura del líquido.
- Controlador de temperatura: Este controlador es utilizado como un indicador de temperatura, sin aprovechar su capacidad de realizar una acción de control.
- Flujómetro (Dosificador): Utilizado para la medición del caudal y volumen del líquido.
- Electroválvulas: Permiten el cierre o paso del líquido por la red de cañerías.
- Variador de frecuencia: Permite regular la velocidad de giro del motor, mediante la variación de frecuencia del mismo, de manera que se pueda bombear el líquido del tanque inferior al superior.
- Motor. (bomba) Actuador encargado de llevar el líquido del tanque inferior al tanque superior para el llenado y control del mismo.
- PLC / Modulo de expansión: Es el controlador del sistema de nivel de líquido, el cual recibe señales de los sensores de nivel para accionar el variador de frecuencia el cual regula la velocidad del motor.
- HMI: Este dispositivo nos permite la visualización de las medidas, escaladas por el PLC, en la parte frontal del panel de control.
  3.4. Puesta en marcha del Sistema

Para la puesta en funcionamiento y energización del sistema se deben seguir los siguientes pasos:

- Energizar al sistema mediante su cable conector a 220 VAC.
- Activar el interruptor principal, ubicado en el costado derecho de la planta.
- Una vez energizado la planta se observa que tanto el dosificador como el controlador de temperatura están ya activos. Sin embargo, para completar con la puesta en funcionamiento y energización de la planta se debe activar los tres térmicos ubicados dentro del panel de control donde:
1) BR1: Térmico encargado de la energización y activación del PLC
2) BR2: Térmico encargado de la energización de la fuente de alimentación y de los sensores que dependan de esta.
3) BR3: Térmico encargado de la energización del variador de frecuencia.

BR1

BR2

BR3

Interruptor principal de la planta

(ubicado al costado derecho de la planta)

Térmicos de activación del sistema

(ubicados dentro del panel de control)

A continuación, se muestra y presenta al sistema como tal, mostrando visualmente los dispositivos, sensores, actuadores, controladores e indicadores que conforman al mismo.

En la figura se muestra una vista frontal del sistema, el panel de control por delante y por dentro, además de los elementos que la conforman.


En la figura se muestra una vista inferior donde se encuentra el motor bomba de la planta.

También se muestra la vista trasera del sistema, donde están ubicados varios de los sensores descritos anteriormente, además que se los señala por colores de que elementos o dispositivos se trata. Y finalmente se muestra la ubicación de los sensores de nivel al costado izquierdo y parte superior del tanque que almacena el líquido.


  3.5. Esquema P&ID

El diagrama o esquema de tuberías P&ID que especifica el sistema de nivel de líquido es realizado con ayuda de la herramienta “AutoCAD Electrical”, donde la simbología, numeración, especificación de líneas, conexiones y lazos de control se realizó en base a la norma ISA.


En la siguiente figura se especifica las señales de instrumentación, la función de cada instrumento, las letras identificadoras y la simbología usada en la representación del sistema


Simbología de instrumentación utilizada

  3.6. Función de transferencia

El esquema presentado a continuación corresponde a un sistema básico de nivel de líquido:


Donde:

- C=Capacitancia del tanque
- R=Resistencia al paso del liquido
- q_i (t)=Caudal de entrada
- q_0 (t)=Caudal de salida
- h(t)=Altura del liquido

Para encontrar una función de transferencia que represente al sistema debemos utilizar ecuaciones diferenciales ordinarias:

C (dh)/(dt)=q_i (t)-q_0 (t)…(1) q_0 (t)=(h(t))/R…(2)

Utilizando la transformada de Laplace conseguimos la función de transferencia:

C sH(s)=Q_i (s)-Q_0 (s)…(1^(') ) Q_0 (s)=(H(s))/R…(2')

Reemplazamos (2’) en (1’)

C sH(s)=Q_i (s)-(H(s))/R → H(s)(Cs+1/R)=Q_i (s) → (H(s))/(Q_i (s))=(1/C)/(s+1/(CR))

Como se puede observar el sistema es de primer orden lineal y estacionario.

El tanque tiene un área de 40x40cm, por lo que la capacitancia del tanque es de 0.16 m2; de esta manera la única variable que nos falta por determinar es la resistencia al paso del líquido “R” pues este valor depende del diámetro de la cañería y de la apertura de las válvulas manuales.
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

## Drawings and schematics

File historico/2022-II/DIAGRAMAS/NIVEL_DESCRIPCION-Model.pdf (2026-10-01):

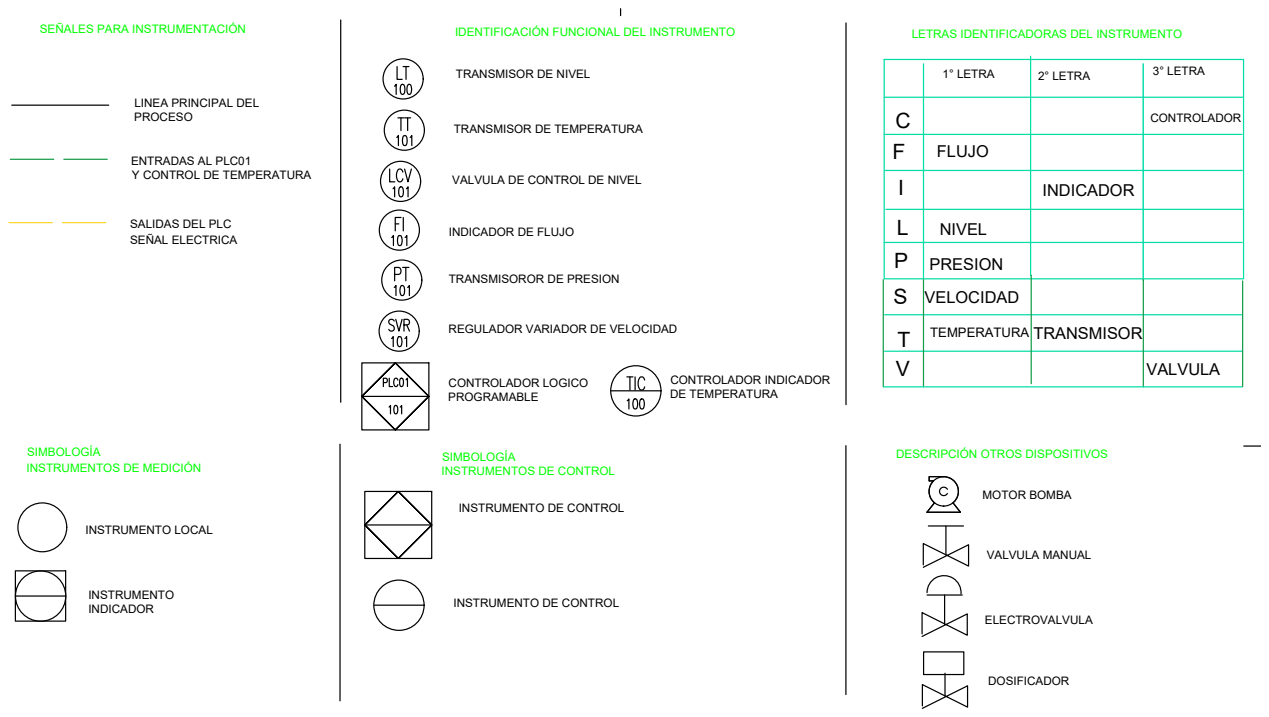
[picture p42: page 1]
SEÑALES PARA INSTRUMENTACIÓN; IDENTIFICACIÓN FUNCIONAL DEL INSTRUMENTO; LETRAS IDENTIFICADORAS DEL INSTRUMENTO SIMBOLOGÍA INSTRUMENTOS DE MEDICIÓN; SIMBOLOGÍA INSTRUMENTOS DE CONTROL; DESCRIPCIÓN OTROS DISPOSITIVOS LINEA PRINCIPAL DEL PROCESO ENTRADAS AL PLC01 Y CONTROL DE TEMPERATURA SALIDAS DEL PLC SEÑAL ELECTRICA; TRANSMISOR DE NIVEL CONTROLADOR LOGICO PROGRAMABLE; MOTOR BOMBA INSTRUMENTO LOCAL; INSTRUMENTO DE CONTROL; 1° LETRA; 2° LETRA; 3° LETRA SLP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

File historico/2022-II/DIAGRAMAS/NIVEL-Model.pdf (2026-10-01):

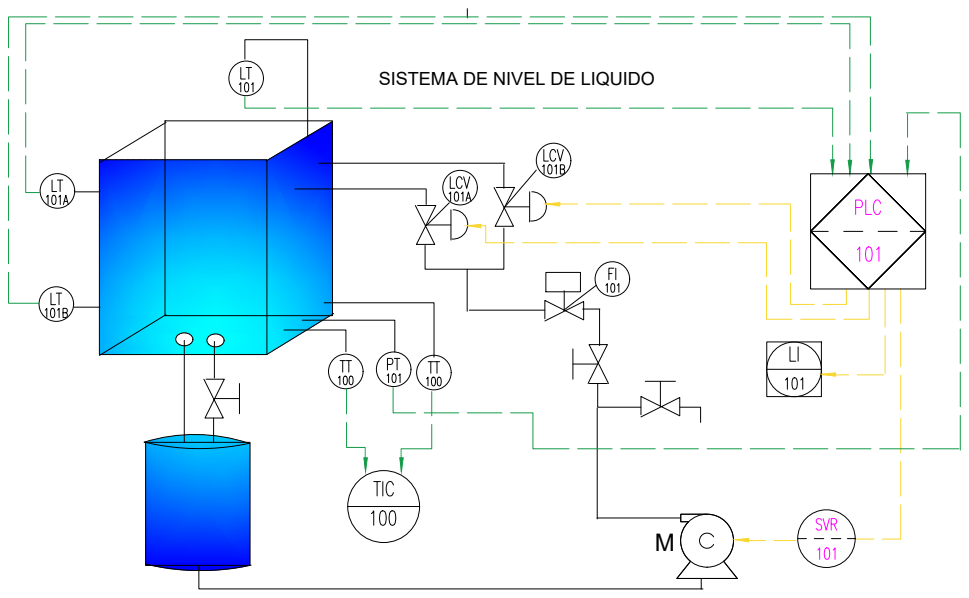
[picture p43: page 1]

SISTEMA DE NIVEL DE LIQUIDO

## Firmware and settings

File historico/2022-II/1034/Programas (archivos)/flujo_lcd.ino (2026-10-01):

//#include <Wire.h> //incluimos las librerias para manejar la pantalla lcd
#include <LiquidCrystal_I2C.h> 

LiquidCrystal_I2C lcd (0x27,16,2); // Creamos un objeto que indicara la direccion del lcd y sus dimensiones
int Calc;
volatile int rpmcount;

void setup() {
  Serial.begin(9600);  //baudrate
  lcd.init();
  lcd.backlight();
  lcd.clear();
  rpmcount=0;
  attachInterrupt(0, rpm, RISING);  //DIGITAL Pin 2: Interrupt 0
}

void rpm()   //measure the quantity of square wave
{
  rpmcount++;
}
void loop() {

  rpmcount=0;
  //sei();
  delay(1000);
  //cli();
  Calc = (rpmcount * 60 / 350);
  Serial.print(Calc);
  Serial.print(" L/min\r\n");
  lcd.backlight();
  lcd.setCursor(0, 0); // mostramos en la primera fila el caudal
  lcd.print("Caudal:");
  lcd.print(Calc);
  lcd.print(" L/min  ");
  lcd.setCursor(0, 1); //mostramos en la segunda fila la revoluciones por segundo
  lcd.print("Re.min:");
  lcd.print(rpmcount);
  lcd.print(" rpm  ");
  attachInterrupt(0, rpm, RISING);  //DIGITAL Pin 2: Interrupt 0
  
}

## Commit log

2026-10-01 docs(historico): indice de semestres con enlaces a Drive
2026-10-01 docs(historico): documentacion del semestre 2022-II
    [NIVEL.dwg, NIVEL_DESCRIPCION.dwg]
